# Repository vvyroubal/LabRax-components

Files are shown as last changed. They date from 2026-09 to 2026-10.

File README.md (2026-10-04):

# Lab Rax 1U device brackets

*someone might find it useful :-)*

**1U brackets for a [Lab Rax 10" rack](https://makerworld.com/en/models/1464819-lab-rax-10-server-rack-bolted-version-5u),
bolted to the front *and* rear posts.**

Lab Rax itself — the racks, panels and the rest of the system these brackets
fit into — is the [Lab Rax collection on MakerWorld](https://makerworld.com/en/collections/5813742-lab-rax).

**Everything prints on a Bambu Lab A1 mini.** Its 180 × 180 × 180 mm bed is
the design limit for every part, and each device's 3MF comes already plated
for it.

<p>
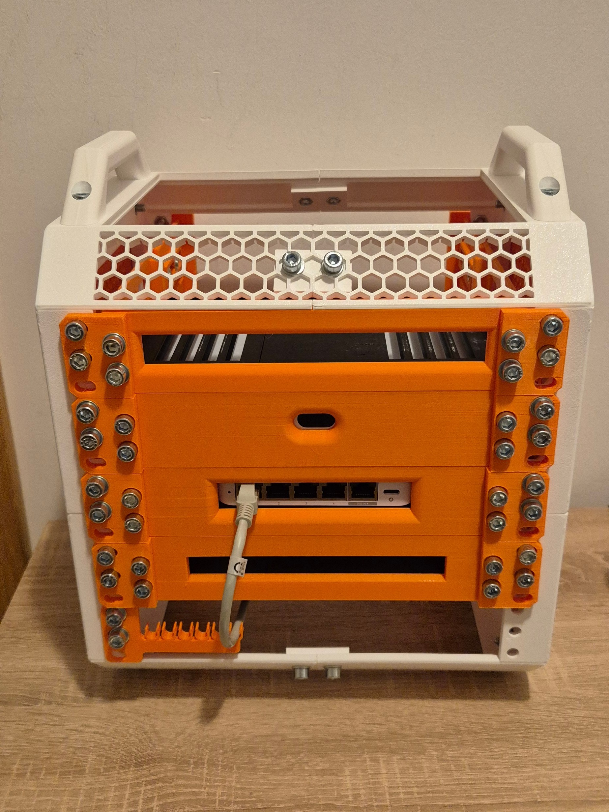
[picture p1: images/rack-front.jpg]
Four brackets in a Lab Rax rack, from the front

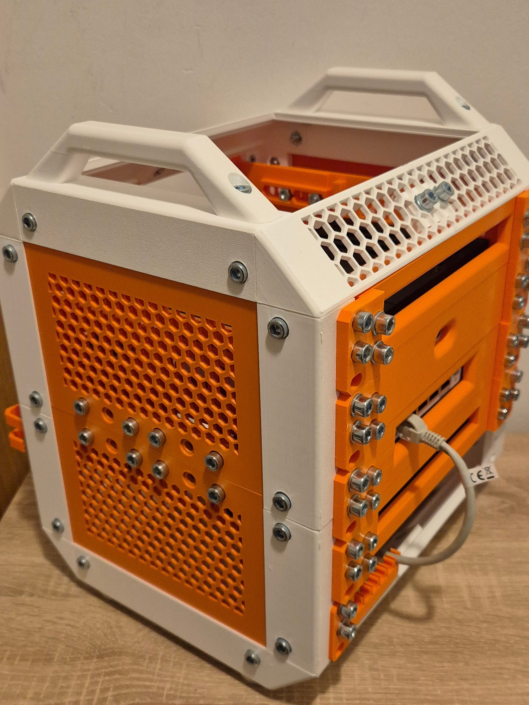
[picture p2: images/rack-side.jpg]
The same rack from the side

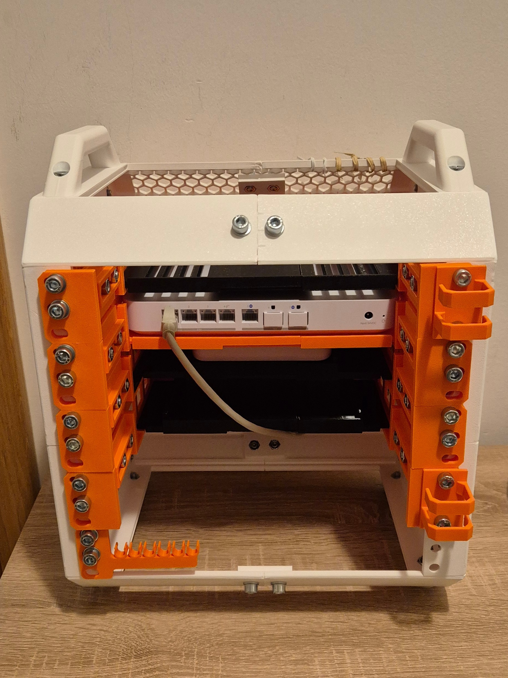
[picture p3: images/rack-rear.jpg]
The same rack from the back

</p>

*Four of these brackets in a Lab Rax, from the front, the side and the back.*

## Quick start

You do not need FreeCAD, Python or anything else in this repository to print
a bracket. The 3MF files are complete.

1. **Print.** Open the 3MF in your device's folder in Bambu Studio and print
   all six plates, in PETG. See [Printing](#printing).
2. **Buy.** 16 × M6 × 12 button-head screws, 4 × M6 nuts, 12 × M6 washers.
   See [Fasteners](#fasteners).
3. **Assemble.** Legs onto the rear posts; sides, tray, device and faceplate
   built on the bench and slid in from the front. See [Assembly](#assembly).

Before committing to the long prints, read [Before you print](#before-you-print):
two small test pieces tell you whether the sliding joint fits on your printer.

## What you can mount

| device | model code | size (mm) | faces the front | print |
|---|---|---|---|---|
| **UniFi Cloud Gateway Fiber** | `UCG-Fiber` | 212.8 × 127.6 × 30, 734 g | its 0.96" display, through an oval window | `ucg-fiber/UCG_Fiber_LabRax-A1mini.3mf` |
| **UniFi Flex Mini 2.5G** | `USW-Flex-2.5G-5` | 117.1 × 90 × 21.2, 206 g | its 5 × 2.5 GbE ports, through an open frame | `usw-flex-mini/USW_Flex_LabRax-A1mini.3mf` |
| **TP-Link Easy Smart switch** | `TL-SG108E` | 158 × 101 × 25 | its 8 × GbE ports, through an open frame | `tl-sg108e/TL_SG108E_LabRax-A1mini.3mf` |
| **Intel NUC, Skull Canyon** | `NUC6i7KYK` | 211 × 116 × 28, 45 W | its front USB and audio, through an open frame | `nuc6i7kyk/NUC6i7KYK_LabRax-A1mini.3mf` |

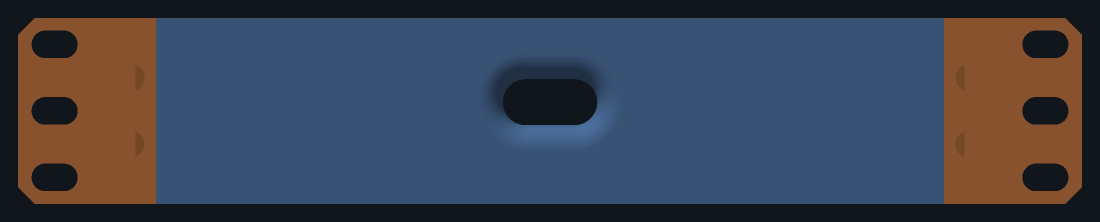
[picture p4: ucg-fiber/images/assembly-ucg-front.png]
the gateway

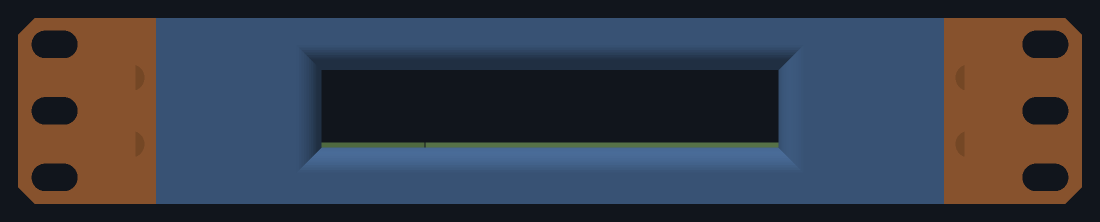
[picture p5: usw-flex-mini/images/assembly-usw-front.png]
the Flex Mini

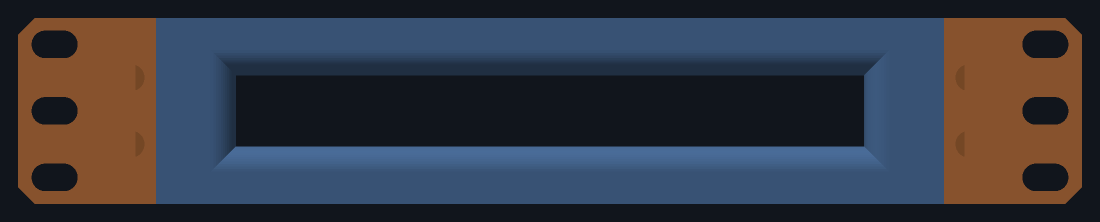
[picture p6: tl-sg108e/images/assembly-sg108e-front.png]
the TP-Link

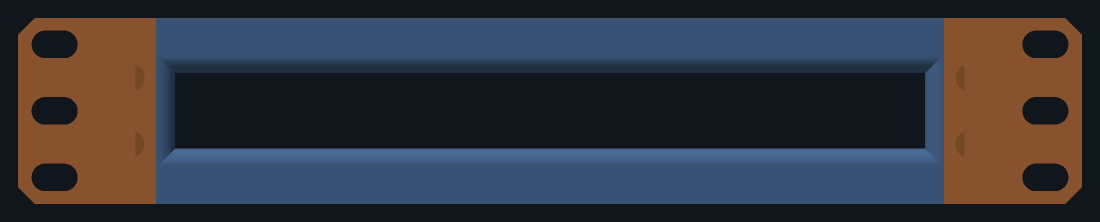
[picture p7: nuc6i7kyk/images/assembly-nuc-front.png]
the NUC


### Will mine fit?

Anything inside this envelope can be carried by the same chassis. It needs a
new device folder with a `device.py` profile in it, and three prints of its
own — see [Adding a device](#adding-a-device).

| | limit | set by |
|---|---|---|
| width | **up to 212.8 mm** | the bay between the rails, 214.0 less clearance |
| depth | **up to 127.6 mm** | the sides' rear stops, 129 mm behind the faceplate |
| height | **up to 33.65 mm** | 1U, less the tray and a flange to cap the device |
| weight | the gateway's 734 g is the heaviest modelled | a 214 × 132 × 6 tray deflects about 0.2 mm under it |
| cooling | passive, or drawing air from underneath | a tray can be slotted, but the front is closed apart from its opening |

A device that fills the bay is held straight by the sides' own rails. One
narrower than **210.8 mm** gets walls on its tray instead, and those walls
need the device to be **204 mm or less**, so widths between about 204 and
210.8 mm are the one gap in the range. A device shorter than the U gets a
plinth under it to centre it in the opening. The faceplate is either a
**window** onto a display or a **frame** onto ports.

What it cannot do: anything over 1U, anything deeper than the rear stops
allow, or anything needing full access to both long faces at once. The
faceplate closes the front apart from its opening, so the busier face has to
go to the back.

## Parts

Seven prints for one device, none over a 180 mm bed.

| part | size (mm) | qty | kit |
|---|---|---|---|
| `side_l` / `side_r` | 33 × 212.5 × 44.5 | 1 each | chassis |
| `leg_l` / `leg_r` | 33 × 91.5 × 44.5 | 1 each | chassis |
| `tray_ucg_l` / `tray_ucg_r` | 136.5 × 131.4 × 9 | 1 each | UCG-Fiber |
| `faceplate_ucg` | 213.6 × 20 × 44.5 | 1 | UCG-Fiber |
| `tray_usw_l` / `tray_usw_r` | 136.5 × 128.4 × 19.6 | 1 each | Flex Mini |
| `faceplate_usw` | 213.6 × 20 × 44.5 | 1 | Flex Mini |
| `tray_sg108e_l` / `tray_sg108e_r` | 136.5 × 128.4 × 17.7 | 1 each | TL-SG108E |
| `faceplate_sg108e` | 213.6 × 20 × 44.5 | 1 | TL-SG108E |
| `tray_nuc_l` / `tray_nuc_r` | 136.5 × 128.4 × 11.2 | 1 each | NUC6i7KYK |
| `faceplate_nuc` | 213.6 × 20 × 44.5 | 1 | NUC6i7KYK |

**Four of the seven are a chassis that takes no notice of what is in it.**
The sides and the rear legs are sized by the rack alone; only the tray pair
and the faceplate are drawn around a device. A second device therefore costs
three prints rather than seven.

A **side** carries the front ear, the side rail, the ledge the tray lands on,
a rear stop, and behind that a **dovetail tongue** along the inner face of the
rail. A **rear leg** carries the rear ear and a **groove** that tongue slides
into. There is no screw between them. At the foot of each leg is a sprung
**catch**, and along the bottom of each rail a notch it runs in: the end stop.

The **tray** comes in halves — at 214 mm it will not fit the bed in any
orientation — lapping 60 mm across the centreline, the left half passing
underneath. Four ⌀5 pegs key them, and they take no screw.

The **faceplate** is the front, in one piece. What is cut in it depends on the
device: a window to see a display through, or a frame opening onto ports. A
flange along its top reaches back over the device so it cannot lift. Its four
nuts slide into slots in its two **ends**, where they stay put.

It is not a front cantilever. The gateway is heavy enough that hanging it off
the front posts alone would work the plastic, so each side runs into a rear
leg that reaches the back posts — four mounting points, twelve screws.

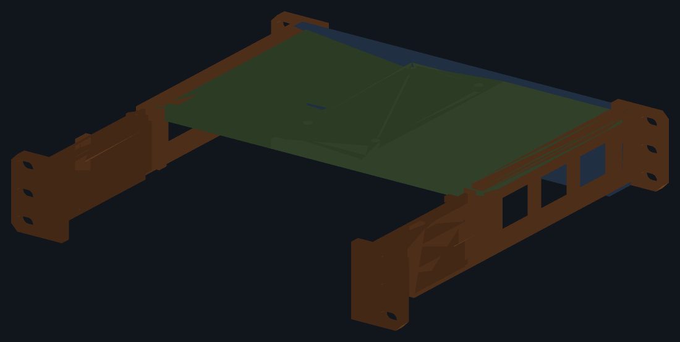
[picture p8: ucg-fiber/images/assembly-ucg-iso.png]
the gateway, assembled


## Printing

**There is one 3MF per device and each carries the chassis too**: six plates,
1–3 the shared chassis, 4–6 that device's own tray pair and faceplate. Open
one, print all six, done. Every plate is labelled in Bambu Studio with the kit
it belongs to. If you build more than one device, plates 1–3 are identical in
every file — print them once per bracket.

| plates | kit | filament | time |
|---|---|---|---|
| 1–3 | chassis (in every file) | 112.1 g | 5 h 46 |
| 4–6 | UCG-Fiber | 149.0 g | 5 h 37 |
| 4–6 | Flex Mini 2.5G | 136.7 g | 5 h 22 |
| 4–6 | TL-SG108E | 142.7 g | 5 h 35 |
| 4–6 | NUC6i7KYK | 133.7 g | 5 h 34 |

A chassis and one kit is about 261 g for the gateway and 249 g for the Flex
Mini. Print in **PETG**: a gateway running IDS/IPS gets warm enough that PLA
is a poor choice around it.

The parts are already turned the way they print: the sides at 45°, the
faceplate stood on edge and upside down so that its flange lies on the bed,
the trays flat. Supports and brims are set per part in the file. Per-plate
figures are in [docs/bom.md](docs/bom.md); settings, orientations and what to
adjust if something is tight are in
[docs/print-settings.md](docs/print-settings.md).

### Before you print

- **Print the two coupons first.** `common/stl/coupon_tongue.stl` and
  `common/stl/coupon_groove.stl` are 25 mm of the side-to-leg runner. Print
  them standing as they are, then slide one into the other. If they bind,
  raise `RUN_FIT` in `common/src/params.py` from 0.25 and rebuild; if they
  rattle, lower it. A dovetail's fit depends on the printer far more than on
  the number, and a side is a two-hour print.
- **Then print one side** and offer it up to the rack. The 0.925 mm per side
  between the rails and the posts is the tightest dimension in the design,
  and a printed rack's post spacing varies.
- **Check the catch moves.** Each leg has a sprung finger at its foot, printed
  flat on the bed with a 1.2 mm slit above it. If the slicer has filled that
  slit with support, clear it out, or the finger cannot move.
- **Measure your device.** Case dimensions are the manufacturers' published
  figures, not calliper measurements, and the weights of the TL-SG108E and
  the NUC are estimates. Before printing a frame faceplate, measure the port
  strip on your unit against the opening given under
  [How each device is held](#how-each-device-is-held).

## Fasteners

**One screw for the whole bracket: M6 × 12.**

| qty | item |
|---|---|
| 16 | M6 × 12 button head |
| 4 | M6 nut — DIN 934, 10 mm across the flats, 5 mm thick |
| 12 | M6 washer — DIN 125 form A, ⌀12.5 |

| qty | where | nut | washer |
|---|---|---|---|
| 12 | bracket to rack: 3 per ear, 4 ears | none — in the post | yes |
| 4 | faceplate, through the front ears | 4 × M6 | no |

The side and the rear leg take none: one slides into the other. The tray
takes none either.

**The rack posts already hold the nuts** for the twelve rack screws, so those
are driven from outside the rack inwards and need no nut of their own.

**The length is not a free choice.** The post's hole is blind at 6 mm, so a
screw that goes more than 6 mm past the ear hits the end and never clamps, and
one that goes much less than 5 mm barely catches the nut. With the ear at
6.5 mm, a 12 mm screw enters 5.5 mm, with 3.5 mm of thread in the nut and half
a millimetre to spare.

**The twelve washers are not optional.** The rack screws go through slots, and
an M6 head is wider than a slot is: without a washer it lands on two crescents
of about 25 mm² and will bury itself in PETG. A washer takes that to
46–60 mm².

**The faceplate's nuts go in from its ends.** Each sits in a slot as tall as
the nut is across its flats, so it cannot turn, and closed in front and
behind, so it cannot fall out. Once the plate is between the sides, the rails
close the open ends too.

## Assembly

Everything with a screw in it is done either behind the rack or on the bench.
No screw has to be reached from inside the rack.

1. **Legs.** Bolt each rear leg to its rear post from behind — three M6 with
   washers — and leave them finger-tight. The grooves face forward.
2. **Nuts.** Slide an M6 nut into each of the four slots in the ends of the
   faceplate, flats top and bottom.
3. **Tray.** On the bench, stand the two sides facing each other and lay the
   tray across their ledges: the **left** half first, then the right half
   onto it, its pegs going down into the left half's sockets. The left half
   cannot be fitted under the right one. The tray spaces the sides.
4. **Device.** Set it straight down onto the tray, its back inside the tray's
   rear lip.
5. **Faceplate.** Lower it from above, behind the ears and in front of the
   device, until its flange sits over the device, and put four M6 through the
   ears into its nuts. It goes on **after** the device: the flange covers the
   device's front edge, and the device cannot be got in underneath it.
6. **Slide it in.** Offer the whole frame to the front of the rack and push:
   each side's tongue runs into its leg's groove, which opens out over its
   first 4 mm to catch it. About 35 mm from home the two catches click into
   their notches. Carry on until the front ears meet the posts.
7. **Bolt up.** Six M6 with washers through the front ears, then tighten the
   six at the back.

**The rack's depth sets itself.** The legs are fixed to the rear posts and the
sides to the front ones; the runner between them takes up whatever the
distance is, from 229 to 257 mm over the outside of the posts.

### The end stop

Undo the six front screws and the frame draws forward **35 mm and stops** —
40 on a 230 mm deep rack, 30 on a 240 — with 17 mm of each tongue still in its
groove.

**At the stop the faceplate can go on or come off in the rack.** It stands
wholly in front of the posts there, flange and all, clear of whatever is in
the U above. So the two sides can be slid in on their own until they click,
the faceplate lowered between them from above, behind the ears, and its four
screws put in from the front; or a faceplate changed without taking anything
else out. On a 240 mm rack the margin to a neighbouring bracket's screw heads
is about a millimetre.

That does not get the tray or the device in. They go in from above too, and
before the faceplate, and at 35 mm out most of the bay is still under
whatever is in the U above. With that U empty, everything can be done in the
rack. Otherwise the tray and the device go into the frame on the bench, as in
the steps above.

Seventeen millimetres of tongue locates the frame; it does not carry it.
**Hold the front up while it is at the stop**, or let it rest on what is
below.

**To take the frame right out**, reach in from the back of the rack and push
the two tabs at the foot of the legs towards the middle, then draw it
forward. Each tab is the tip of its catch; a screwdriver does as well as a
finger.

## How each device is held

| | UCG-Fiber | Flex Mini 2.5G | TL-SG108E | NUC6i7KYK |
|---|---|---|---|---|
| lifted by a plinth | no | 5.625 mm | 3.725 mm | 2.225 mm |
| sits at (z) | 6.0 – 36.0 | 11.625 – 32.825 | 9.725 – 34.725 | 8.225 – 36.225 |
| held sideways by | the rails, 0.6 mm a side | walls on its tray | walls on its tray | the rails, 1.5 mm a side |
| held down by | the faceplate's flange, 0.8 mm over the case | the same | the same | the same |
| held back by | its tray's rear lip | the same | the same | the same |
| opening (mm) | 22.5 × 11.0 window | 109.1 × 18.5 frame | 150 × 17 frame | 179 × 18 frame |
| round-over on the opening | 6 mm | 6 mm | 6 mm | 4 mm |
| tray | solid | solid | solid | slotted for air |

`z` is height above the bottom of the U, which is 44.45 mm tall.

**The gateway** fills the bay, so the rails hold it straight and the ears
overlap its ends by 12.4 mm. Its display faces front through a 22.5 × 11.0
window, slightly larger than the 21.0 × 10.0 display behind it. The window's
top edge sits 7.0 mm below the underside of the faceplate's flange.

**The Flex Mini** is 96.9 mm narrower than the bay and 8.8 mm shorter than the
gateway, and its ports are what you look at, so its tray carries a plinth
that lifts the case until it is centred in the U, and 4 mm walls that hold it
straight. Its frame leaves a 4 mm border each side, 1.85 mm below and 0.85
above. The opening is not centred on the case: centred, an RJ45 plug with its
latch would not go in, so the extra millimetre comes off the top border.

**The TL-SG108E** is held the same way, with a 4 mm border all round its
opening.

**The NUC** fills the bay like the gateway. Its border is 16 mm at each side
— a narrower one would run into the faceplate's nut slots — and 5 mm above and
below. It draws its cooling air through its underside, so its tray is slotted:
fore-and-aft slots open 27% of the width, floor to case. The centre lap stays
solid, because it is the joint holding the tray's halves together.

A frame's border is what keeps the case in, and it does so absolutely rather
than by friction: the case is wider and taller than the hole.

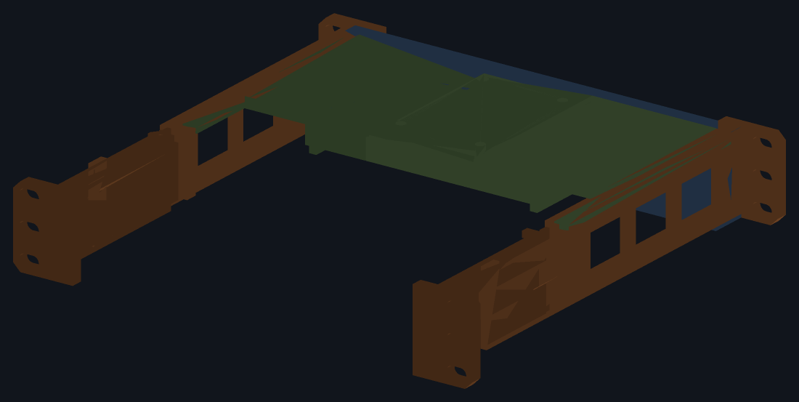
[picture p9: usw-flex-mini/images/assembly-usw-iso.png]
the Flex Mini, assembled


## Orientation and cooling

The gateway's ports and DC input are on one long face and its display on the
other, so its faceplate commits you to **display at the front, cables at the
back**. The two switches are the opposite: **ports at the front**, through the
frame, power at the back. The NUC shows its front USB and audio; everything
else is at the back.

Each side rail carries three windows, and the rear of the bracket is open.
Only the NUC's tray is slotted underneath; the others are solid.

One thing to know about the rear: on the two devices that fill the bay, the
outer 7 mm of each end of the back panel is behind the side's rear stop and
the leg. Keep plugs out of that last 7 mm.

## Compatibility with the rack

Interface numbers were measured off the Lab Rax models themselves rather than
taken from their description, because the published figures are rounded. How
each was obtained is in [docs/measurements.md](docs/measurements.md).

| | value | source |
|---|---|---|
| Faceplate | 254.0 × 44.45 mm (1U) | a Lab Rax 1U mount |
| Screw columns | 236.525 mm apart | rack posts |
| Hole heights in the U | 6.35 / 22.225 / 38.1 mm | EIA-310, confirmed on the posts |
| Screws | M6 | Lab Rax uses M6 throughout |
| Clear width between posts | 222.25 mm | derived from the post holes |
| Clear depth between posts | 170.0 mm | three frame members in the rack's 3MF |
| Front posts to rear posts | 230 or 240 mm outer | 170.0 plus two posts, 30 or 35 mm each |

**The bracket's width comes from the rack.** The posts leave 222.25 mm between
them; 0.925 mm of clearance a side and a 3.2 mm rail give a bay 214.0 mm wide.

**The ears carry clearance slots**, 11.0 × 6.6 mm, giving ±2.3 mm of sideways
adjustment.

**Depth is not a number to trust.** The post's section is 30 × 35 mm and the
mesh does not say which way it faces, so the outer depth is either 230 or
240 mm. The model takes 235 as nominal, and the runner covers 229 – 257 mm:
6 mm shallower than nominal before the leg meets the side's rear stop, 22 mm
deeper before less than 30 mm of tongue is left in the groove.

## Building from source

The parts are modelled in **FreeCAD**, generated by script rather than drawn.
`common/src/params.py` holds every dimension, each device's folder a
`device.py` profile, and `common/src/model.py` builds the bodies from them.
Each part is a PartDesign **Body** of **sketches** driving a **pad** or
**pocket**, so the documents open as something you can edit feature by
feature.

You need:

- **FreeCAD 1.x**, for `make`, `make verify` and `make assembly`. The
  Makefile runs it as a flatpak; set `FREECAD` to your own `freecadcmd` if
  yours is installed another way.
- **Python 3 with NumPy**, for the renders and the plated 3MFs.
- **Bambu Studio**, only for `make plates`. It is also run as a flatpak; set
  `BAMBU` to override.

```sh
make            # build, verify, check fasteners, render, plate
make verify     # re-check the solids against the rack, each device and the bed
make assembly   # put real M6 x 12 screws, nuts and washers in and check them
make plate      # one 3MF in each device's folder, for Bambu Studio
make plates     # slice every plate for real and measure the toolpaths
```

Every `.FCStd` and `.step` embeds a build timestamp, so `make` leaves them
looking modified even when nothing changed. The 3MFs and the STLs are
reproducible. Discard that churn with `git checkout -- '*.FCStd' '*.step'`.

### Adding a device

Add a folder with a `device.py` in it and name that folder in `DIRS` in
`common/src/devices.py`. Nothing else changes. The profile says:

- the case's width, depth and height, and its mass;
- `doc`, what its FreeCAD document and STEP are called;
- `plinth`, how far to lift it above the tray;
- `front`, a `Window` or a `Frame`, with an optional `fillet` to round over
  the opening's front edge;
- `vent=True` if it breathes through its underside and wants a slotted tray.

Then add its three plates to `KITS` in `common/tools/plate.py` and run `make`.

### What is checked

`make verify` measures the **built solids**, not the parameters, so a feature
that silently does nothing is caught rather than assumed away: 197 checks for
the NUC, 194 for the gateway, 193 each for the Flex Mini and the TL-SG108E.
Among them:

- each body is one valid solid, built from sketches, and fits the bed;
- no two parts overlap, and the faceplate and tray still clear what is beside
  them when they are *moved* a fraction of a millimetre, not just where they
  are drawn;
- an M6 passes all twelve rack slots and does not bottom out in the post;
- each leg is held on its tongue every way but along the rack's depth, and
  slides over the whole range claimed;
- the frame stops where it should when drawn out, on racks of either depth,
  and the faceplate can then be lowered into it clear of the U above;
- each faceplate nut slides the length of its slot and is trapped once there;
- the device drops in, is stopped on every face, and cannot be pushed out of
  the front.

`make assembly` places a real M6 × 12, nut and washer at each of the sixteen
positions and asks whether they fit what was actually built: 87 checks per
device.

`make plates` slices every plate and reads the toolpath extents back out of
the G-code, because a part that fits the bed and a print that fits the bed
are not the same claim.

All of this is geometry. None of it tests strength, or how a sliding fit
comes out on a particular printer — which is what the two coupons are for.

### Layout

```
common/
  src/
    params.py       every rack and design dimension, tagged [rack] / [design]
    devices.py      the Device / Window / Frame classes; loads each device's
                    profile, and says where each part's files go
    sk.py           sketch plumbing: planes, polygons, slots, pads, pockets,
                    fillets, and finding edges by where they are
    model.py        four chassis bodies plus three per device, and the coupons
  tools/
    verify.py       193 - 197 checks per device against the rack and the bed
    assembly.py     87 checks with real M6 solids at all sixteen positions
    measure_rack.py re-derives the [rack] numbers from the Lab Rax mesh files
    preview.py      renders each device's images/ from its STLs
    plate.py        arranges the STLs onto A1 mini plates as a Bambu 3MF
    checkplates.py  slices every plate for real and measures the toolpaths
  stl/              side_l, side_r, leg_l, leg_r, and the two test coupons
  cad/  step/       one FreeCAD document and STEP holding every part of every
                    device (it is called UCG_Fiber_LabRax)
ucg-fiber/          one folder per device:
  device.py           its profile: case, mass, plinth, front opening
  stl/                its tray pair and faceplate
  *.FCStd  *.step     the chassis and its three parts, as FreeCAD and STEP
  *.3mf               the chassis and its kit, plated for the A1 mini
  images/             renders of it assembled, and the pictures for MakerWorld
  docs/MAKERWORLD.md  the text posted with that 3MF on MakerWorld
usw-flex-mini/  tl-sg108e/  nuc6i7kyk/
build.py            writes every FCStd, STEP and STL
images/             photographs of the brackets fitted in a rack
docs/
  bom.md            what to print and what to buy, plate by plate
  measurements.md   where the rack's numbers came from
  print-settings.md settings, orientations and fit adjustment
```

## License

MIT; see [LICENSE](LICENSE). Lab Rax itself is not part of this repository
and is published under its own terms on MakerWorld.

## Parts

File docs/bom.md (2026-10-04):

# What to print and what to buy

The print figures here are read out of a real slice and the sizes off the
built solids — nothing is estimated. `make plates` re-slices every plate.

## Print

**Four parts are the chassis and serve every device; three more are that
device's own.** There is one 3MF per device, and each carries the chassis as
well, so whichever you open is a complete build: print all six plates.

| file | plates | filament, time |
|---|---|---|
| `ucg-fiber/UCG_Fiber_LabRax-A1mini.3mf` | 1–3 chassis, 4–6 UCG-Fiber | 261.0 g, 11 h 23 |
| `usw-flex-mini/USW_Flex_LabRax-A1mini.3mf` | 1–3 chassis, 4–6 USW-Flex | 248.7 g, 11 h 09 |
| `tl-sg108e/TL_SG108E_LabRax-A1mini.3mf` | 1–3 chassis, 4–6 TL-SG108E | 254.7 g, 11 h 22 |
| `nuc6i7kyk/NUC6i7KYK_LabRax-A1mini.3mf` | 1–3 chassis, 4–6 NUC6i7KYK | 245.8 g, 11 h 21 |

Every plate carries its own label in Bambu Studio — `Chassis 2 of 3 - right
side`, `UCG-Fiber 3 of 3 - faceplate` — so the tab tells you which kit a plate
belongs to.

| kit | parts | filament | time |
|---|---|---|---|
| chassis | `side_l`, `side_r`, `leg_l`, `leg_r` | 112.1 g | 5 h 46 |
| UCG-Fiber | `tray_ucg_l`, `tray_ucg_r`, `faceplate_ucg` | 149.0 g | 5 h 37 |
| USW-Flex-2.5G-5 | `tray_usw_l`, `tray_usw_r`, `faceplate_usw` | 136.7 g | 5 h 22 |
| TL-SG108E | `tray_sg108e_l`, `tray_sg108e_r`, `faceplate_sg108e` | 142.7 g | 5 h 35 |
| NUC6i7KYK | `tray_nuc_l`, `tray_nuc_r`, `faceplate_nuc` | 133.7 g | 5 h 34 |

**Each bracket needs a chassis of its own.** Plates 1–3 are identical in all
four files, so for a second device print them again from whichever file is
open, then that device's plates 4–6.

Plate by plate:

| plate | part | size (mm) | filament | time | support |
|---|---|---|---|---|---|
| 1 | `side_l` | 33 × 212.5 × 44.5 | 36.1 g | 1 h 56 | yes |
| 2 | `side_r` | 33 × 212.5 × 44.5 | 36.1 g | 1 h 56 | yes |
| 3 | `leg_l` + `leg_r` | 33 × 91.5 × 44.5 each | 40.0 g | 1 h 55 | yes |
| 4 | `tray_ucg_l` | 136.5 × 131.4 × 9 | 49.0 g | 1 h 45 | yes |
| 5 | `tray_ucg_r` | 136.5 × 131.4 × 9 | 57.3 g | 2 h 07 | yes |
| 6 | `faceplate_ucg` | 213.6 × 20 × 44.5 | 42.7 g | 1 h 45 | no |
| 4* | `tray_usw_l` | 136.5 × 128.4 × 19.6 | 42.5 g | 1 h 37 | yes |
| 5* | `tray_usw_r` | 136.5 × 128.4 × 19.6 | 55.5 g | 2 h 05 | yes |
| 6* | `faceplate_usw` | 213.6 × 20 × 44.5 | 38.6 g | 1 h 40 | no |
| 4† | `tray_sg108e_l` | 136.5 × 128.4 × 17.7 | 47.3 g | 1 h 45 | yes |
| 5† | `tray_sg108e_r` | 136.5 × 128.4 × 17.7 | 59.2 g | 2 h 12 | yes |
| 6† | `faceplate_sg108e` | 213.6 × 20 × 44.5 | 36.2 g | 1 h 38 | no |
| 4‡ | `tray_nuc_l` | 136.5 × 128.4 × 11.2 | 44.4 g | 1 h 45 | yes |
| 5‡ | `tray_nuc_r` | 136.5 × 128.4 × 11.2 | 55.4 g | 2 h 12 | yes |
| 6‡ | `faceplate_nuc` | 213.6 × 20 × 44.5 | 33.9 g | 1 h 37 | no |

\* in `USW_Flex_LabRax-A1mini.3mf`, † in `TL_SG108E_LabRax-A1mini.3mf`,
‡ in `NUC6i7KYK_LabRax-A1mini.3mf`; the rows with no mark are in
`UCG_Fiber_LabRax-A1mini.3mf`.

Figures are for PETG at 0.2 mm layers with the profile the 3MFs carry — see
[print-settings.md](print-settings.md).

**Print the two runner coupons first.** `common/stl/coupon_tongue.stl` and
`common/stl/coupon_groove.stl` are 25 mm of the joint between a side and its
leg, and small. They are not in the 3MFs: drop the two STLs
onto a plate in Bambu Studio as they are. The README says what to do with
them.

## Buy

| qty | item |
|---|---|
| **16** | **M6 × 12 button head** |
| **4** | **M6 nut** (DIN 934, 10 mm across the flats, 5 mm thick) |
| **12** | **M6 washer** (DIN 125 form A, ⌀12.5, 1.6 thick) |

That is for one bracket. One screw length does for all of it.

| qty | where | nut | washer |
|---|---|---|---|
| 12 | bracket to rack: 3 per ear, 4 ears | none — in the post | yes |
| 4 | faceplate, through the front ears | 4 × M6 | no |

The twelve rack screws need no nuts: the Lab Rax posts already hold them. The
side and the rear leg take no screw, because the side's tongue slides into
the leg's groove, and neither does the tray, whose halves are keyed by four
pegs.

**The twelve washers are not optional.** Every one of the rack screws goes
through a slot 6.6 mm wide, and an M6 button head is 10.5 across. Without a
washer the head lands on two thin crescents beside the slot, about 25 mm² of
PETG, and tightening will bury it. A ⌀12.5 washer spreads that to 46–60 mm²,
which is what the four faceplate screws, in round counterbored holes, already
have.

### Why 12 mm

The binding constraint is the rack post. Its equipment hole is **blind at
6 mm**: 2 mm of ⌀7.6 clearance, then a 4 mm hex pocket holding the nut. A
screw that goes in more than 6 mm past the ear hits the end of the hole and
never clamps; one that goes in less than about 5 mm barely catches the nut.

That fixes the ear thickness. At **6.5 mm**, a 12 mm screw enters the post
5.5 mm — half a millimetre clear of the bottom — with 3.5 mm of thread in the
nut. Thicker ears and the screw cannot reach; thinner and it bottoms out.

The faceplate is arranged around the same screw:

| joint | how it is made to fit | thread in the nut |
|---|---|---|
| rack | ear 6.5 mm, into the post's own nut | 3.5 mm |
| faceplate | head sunk 1 mm into the ear, nut 1.5 mm behind the plate's front face | 5.0 mm |

`make verify` checks both on every build: that each screw reaches its nut
with at least 3 mm of thread, and that the rack screw does not bottom out.
`make assembly` goes further and puts a real screw, nut and washer at all
sixteen positions, reporting the seat area under each head.

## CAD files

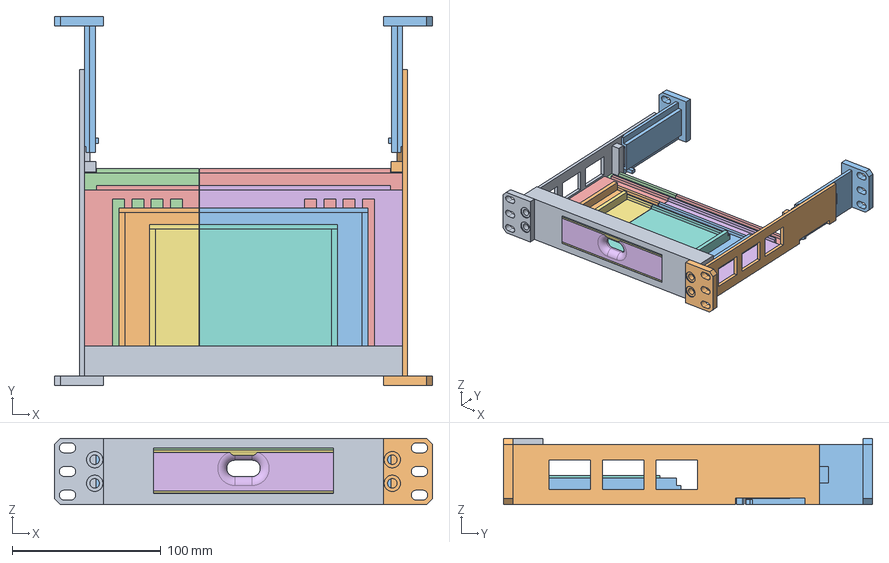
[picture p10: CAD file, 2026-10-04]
common/step/UCG_Fiber_LabRax.step
254.0 x 248.0 x 44.5 mm

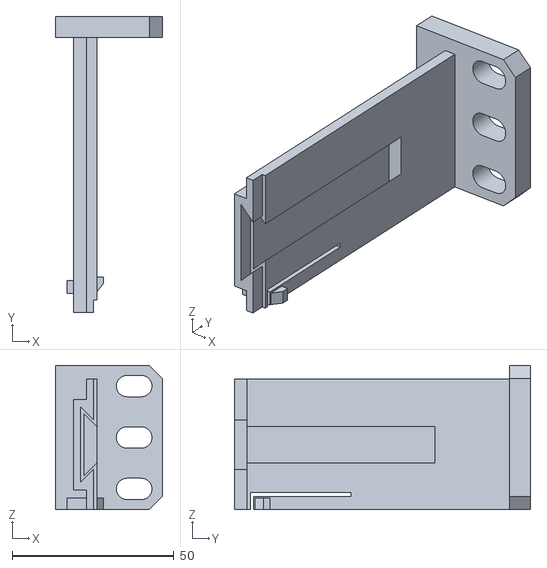
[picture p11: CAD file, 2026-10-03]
common/stl/leg_r.stl
33.0 x 91.5 x 44.5

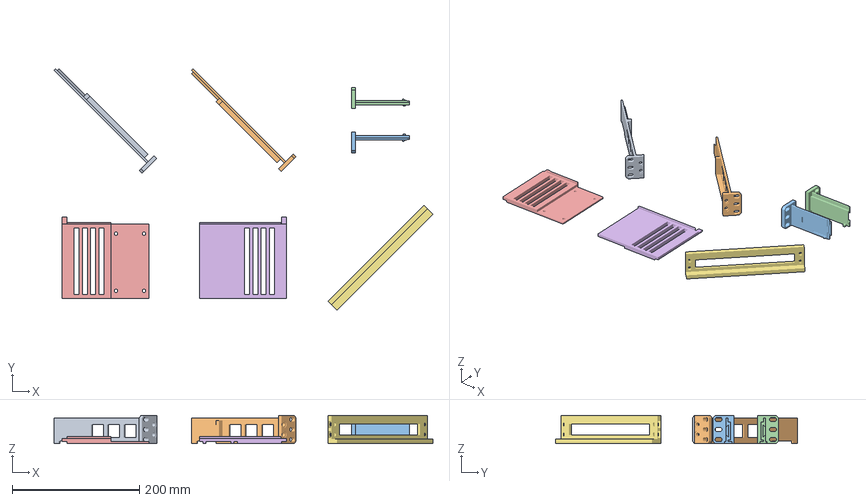
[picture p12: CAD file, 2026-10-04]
nuc6i7kyk/NUC6i7KYK_LabRax-A1mini.3mf
595.4 x 379.4 x 44.5 mm
side_l.stl
side_r.stl
leg_l.stl
leg_r.stl
tray_nuc_l.stl
tray_nuc_r.stl
faceplate_nuc.stl

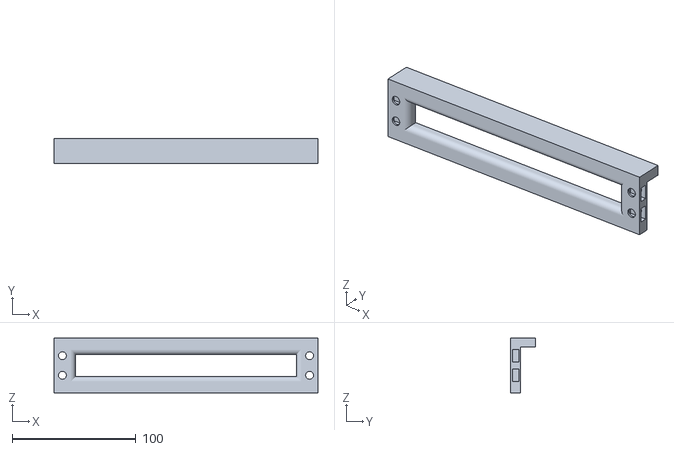
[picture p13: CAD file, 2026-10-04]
nuc6i7kyk/stl/faceplate_nuc.stl
213.6 x 20.0 x 44.5

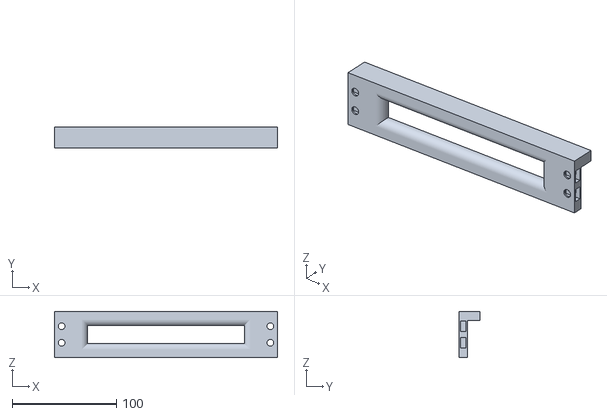
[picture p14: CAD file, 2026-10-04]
tl-sg108e/stl/faceplate_sg108e.stl
213.6 x 20.0 x 44.5

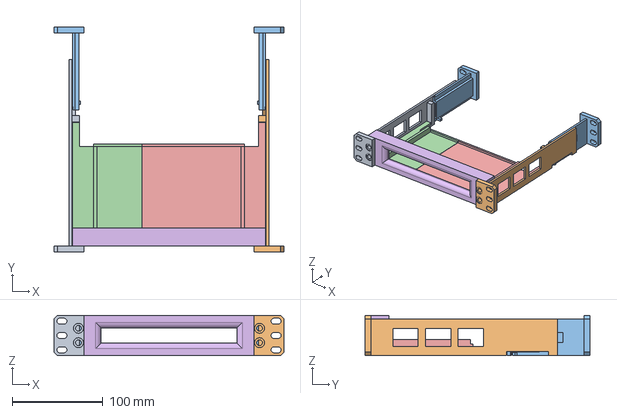
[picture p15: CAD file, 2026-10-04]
tl-sg108e/TL_SG108E_LabRax.step
254.0 x 248.0 x 44.5 mm

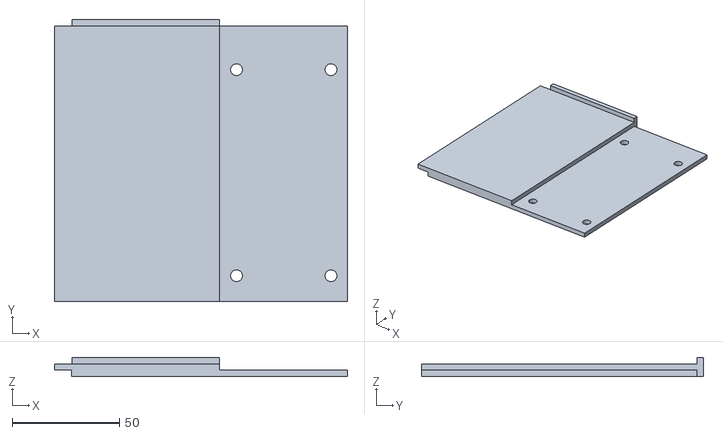
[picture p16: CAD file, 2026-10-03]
ucg-fiber/stl/tray_ucg_l.stl
136.5 x 131.4 x 9.00

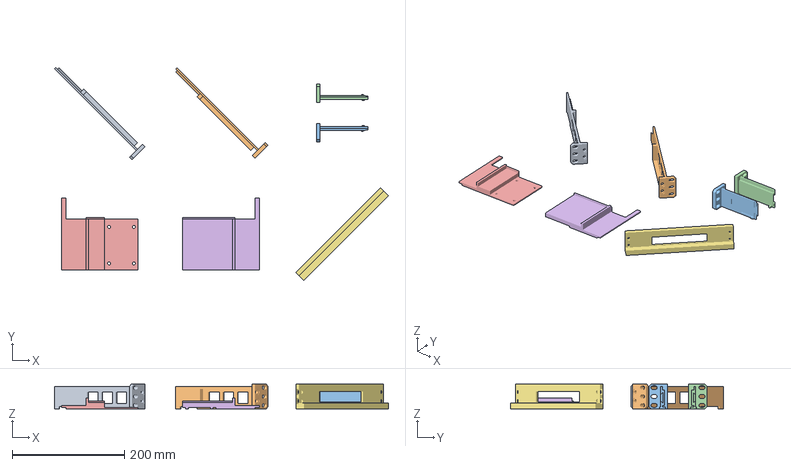
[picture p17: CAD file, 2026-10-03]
usw-flex-mini/USW_Flex_LabRax-A1mini.3mf
595.4 x 379.4 x 44.5 mm
side_l.stl
side_r.stl
leg_l.stl
leg_r.stl
tray_usw_l.stl
tray_usw_r.stl
faceplate_usw.stl

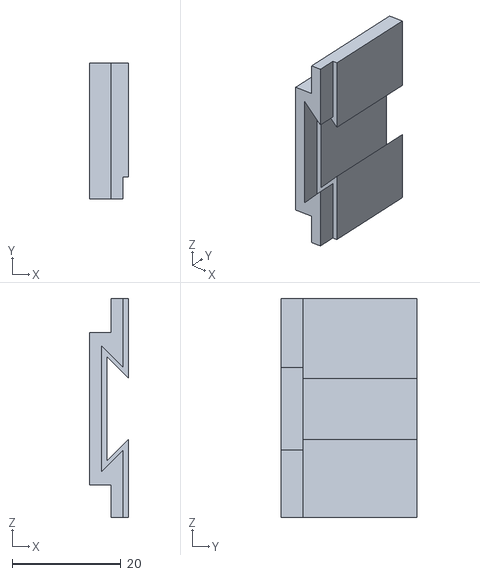
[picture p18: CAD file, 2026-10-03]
common/stl/coupon_groove.stl
7.20 x 25.0 x 40.3

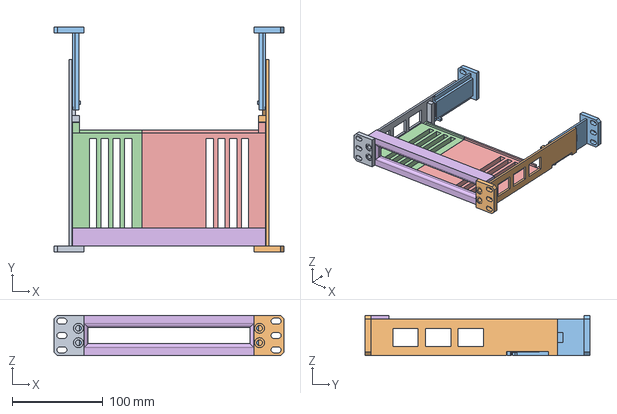
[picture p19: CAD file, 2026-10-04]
nuc6i7kyk/NUC6i7KYK_LabRax.step
254.0 x 248.0 x 44.5 mm

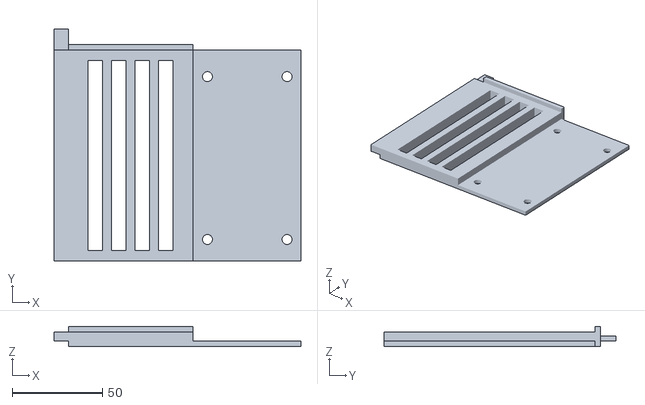
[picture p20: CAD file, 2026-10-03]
nuc6i7kyk/stl/tray_nuc_l.stl
136.5 x 128.4 x 11.2

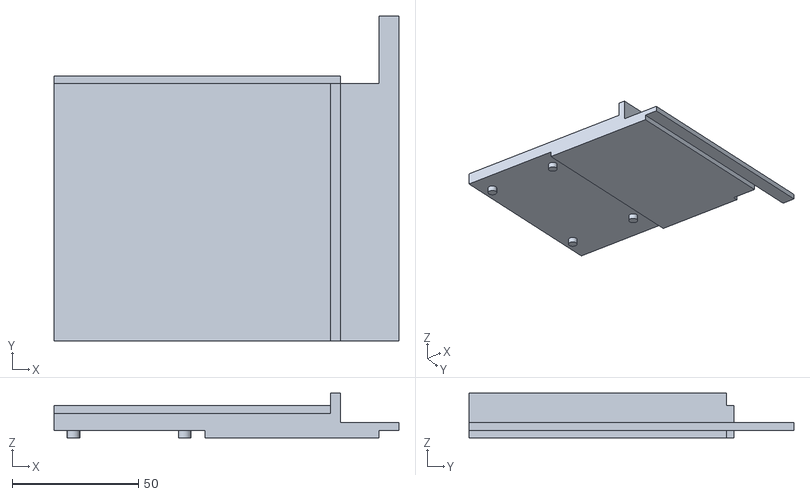
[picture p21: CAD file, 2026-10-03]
tl-sg108e/stl/tray_sg108e_r.stl
136.5 x 128.4 x 17.7

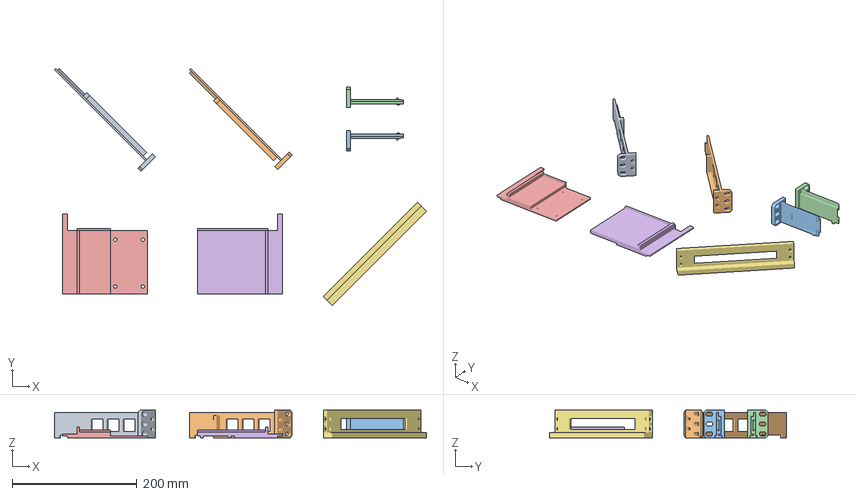
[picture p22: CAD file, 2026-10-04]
tl-sg108e/TL_SG108E_LabRax-A1mini.3mf
595.4 x 379.4 x 44.5 mm
side_l.stl
side_r.stl
leg_l.stl
leg_r.stl
tray_sg108e_l.stl
tray_sg108e_r.stl
faceplate_sg108e.stl

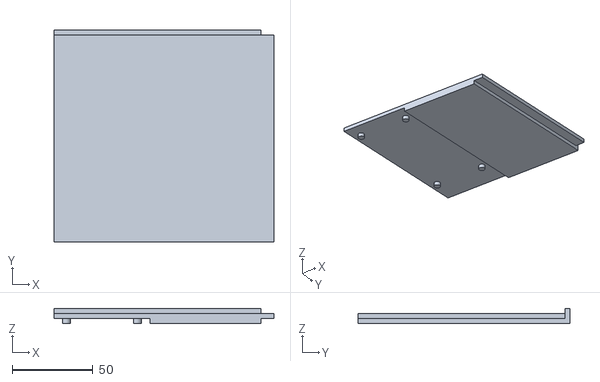
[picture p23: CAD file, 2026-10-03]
ucg-fiber/stl/tray_ucg_r.stl
136.5 x 131.4 x 9.00

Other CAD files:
ucg-fiber/UCG_Fiber_LabRax-A1mini.3mf
usw-flex-mini/stl/faceplate_usw.stl
ucg-fiber/UCG_Fiber_LabRax.step
usw-flex-mini/stl/tray_usw_l.stl
common/cad/UCG_Fiber_LabRax.FCStd
common/stl/coupon_tongue.stl
common/stl/leg_l.stl
common/stl/side_l.stl
common/stl/side_r.stl
nuc6i7kyk/NUC6i7KYK_LabRax.FCStd
nuc6i7kyk/stl/tray_nuc_r.stl
tl-sg108e/TL_SG108E_LabRax.FCStd
tl-sg108e/stl/tray_sg108e_l.stl
ucg-fiber/UCG_Fiber_LabRax.FCStd
ucg-fiber/stl/faceplate_ucg.stl
usw-flex-mini/USW_Flex_LabRax.FCStd
usw-flex-mini/USW_Flex_LabRax.step
usw-flex-mini/stl/tray_usw_r.stl

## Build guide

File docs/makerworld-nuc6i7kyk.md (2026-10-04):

# MakerWorld listing: NUC6i7KYK_LabRax-A1mini.3mf

Text to post with `nuc6i7kyk/NUC6i7KYK_LabRax-A1mini.3mf`. Paste each part into the matching field.

## Title

Lab Rax 1U bracket for Intel NUC6i7KYK (Skull Canyon), A1 mini

## Summary

A 1U bracket that carries an Intel NUC6i7KYK (Skull Canyon) in a Lab Rax 10 inch rack, bolted to the front and rear posts, on a slotted tray that lets it breathe. Every part fits an A1 mini.

## Tags

Lab Rax, 10 inch rack, 1U, Intel NUC, NUC6i7KYK, Skull Canyon, rack mount, homelab, A1 mini

## Pictures

Isometric views from FreeCAD, in `nuc6i7kyk/images/`, 1200 x 1600 (3:4) on white:

1. `makerworld-nuc-assembled.png` — cover picture: the bracket with the
   device in place and all sixteen screws fitted.
2. `makerworld-nuc-empty.png` — the bracket without the device, showing the
   tray and the runners at the back.
3. `makerworld-nuc-exploded.png` — the seven printed parts and the device,
   drawn apart to show how they go together.

The device is shown as a plain translucent block the size of its case.

## Description

**A 1U bracket for the Intel NUC6i7KYK, "Skull Canyon", for a Lab Rax 10 inch rack.**

It bolts to the front and the rear posts, so the device is carried at four
points rather than hung off the front. It goes in like a drawer: two legs
bolt to the rear posts, and the rest is built on the bench and slid in from
the front. No screw has to be reached from inside the rack.

The rack itself is not included. It is the Lab Rax bolted 5U rack:
https://makerworld.com/en/models/1464819-lab-rax-10-server-rack-bolted-version-5u
and the rest of the system is in the Lab Rax collection:
https://makerworld.com/en/collections/5813742-lab-rax

**The device**

Intel NUC6i7KYK, "Skull Canyon", 211 x 116 x 28 mm.

The NUC's front USB ports and audio jack face the front through an open frame in the faceplate, 179 x 18 mm, with a rounded front edge. Everything else is at the back.

The NUC fills the bay, so the bracket's own side rails hold it straight. It draws its cooling air through its underside, so the tray under it is slotted from front to back.

**What is in the file**

Six plates, already arranged for a Bambu Lab A1 mini (180 x 180 mm bed):

- Plate 1: left side
- Plate 2: right side
- Plate 3: both rear legs
- Plate 4: left half of the tray
- Plate 5: right half of the tray
- Plate 6: faceplate

Every part is already turned the way it prints, and supports and brims are
set per part. Open the file and print all six plates.

Plates 1 to 3 are a chassis that is the same for every device in this series.
Plates 4 to 6 are made for this device.

**Printing**

- Material: PETG. PLA will work in a cool room, but a warm device makes it a
  poor choice.
- Profile: 0.20 mm Standard for the A1 mini, as carried in the file. 2 walls,
  15% infill.
- Filament: about 246 g for all six plates.
- Time: about 11 h 21 min for all six plates.

Each rear leg has a small sprung catch at its foot, printed flat on the bed
with a thin slit above it. When the legs come off the plate, check that slit
is clear and pick out any support left in it, or the catch cannot move.

**Hardware to buy**

- 16 x M6 x 12 button head screws
- 4 x M6 nuts
- 12 x M6 washers (12.5 mm outside diameter)

The rack's posts already hold the nuts for the twelve rack screws. The four
loose nuts are for the faceplate. The washers are needed: the rack screws go
through slots, and a bare screw head will sink into the plastic.

**Assembly**

1. Bolt each rear leg to its rear post from behind, three screws with
   washers. Leave them finger-tight. The grooves face forward.
2. Slide a nut into each of the four slots in the ends of the faceplate.
3. On the bench, stand the two sides facing each other and lay the tray
   across their ledges: the left half first, then the right half onto it.
4. Set the device down onto the tray.
5. Lower the faceplate from above, behind the ears and in front of the
   device, and put four screws through the ears into its nuts. The faceplate
   goes on after the device, not before.
6. Slide the whole frame into the rack from the front. Each side runs into
   the groove of its leg. About 35 mm from home the two catches click.
7. Put six screws with washers through the front ears, then tighten the six
   at the back.

To take it out again, undo the six front screws and draw the frame forward.
It stops after about 35 mm. To remove it completely, reach in from the back
of the rack and push the two tabs at the foot of the legs towards the middle.

**Good to know**

- The sides slide into the legs on a printed dovetail, and how freely that
  runs depends on the printer. Two small test pieces for it are on GitHub
  (`common/stl/coupon_tongue.stl` and `coupon_groove.stl`). Print those first:
  they are small, and they tell you whether the fit suits your printer before
  you print a two-hour side.
- The rack's depth sets itself. The joint between side and leg slides, and
  covers 229 to 257 mm over the outside of the posts.
- The gap between the bracket and the rack's posts is under a millimetre a
  side. Print one side first and offer it up to your rack.
- The outer 7 mm at each end of the NUC's back panel sits behind the
  bracket's rear stops. Keep plugs out of that last 7 mm.
- Before printing the faceplate, check the front ports on your unit against
  the 179 x 18 mm opening. Case dimensions are Intel's published figures.

**Source, other devices and full documentation**

https://github.com/vvyroubal/LabRax-components

The parts are generated by a FreeCAD script, so every dimension can be
changed and the files rebuilt. The repository also has the STL, STEP and
FreeCAD files, brackets for other devices on the same chassis, and what to
change if a fit is tight on your printer. MIT licence.

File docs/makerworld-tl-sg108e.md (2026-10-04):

# MakerWorld listing: TL_SG108E_LabRax-A1mini.3mf

Text to post with `tl-sg108e/TL_SG108E_LabRax-A1mini.3mf`. Paste each part into the matching field.

## Title

Lab Rax 1U bracket for TP-Link TL-SG108E, A1 mini

## Summary

A 1U bracket that carries a TP-Link TL-SG108E 8-port switch in a Lab Rax 10 inch rack, bolted to the front and rear posts. Ports at the front. Every part fits an A1 mini.

## Tags

Lab Rax, 10 inch rack, 1U, TP-Link, TL-SG108E, switch, rack mount, homelab, A1 mini

## Pictures

Isometric views from FreeCAD, in `tl-sg108e/images/`, 1200 x 1600 (3:4) on white:

1. `makerworld-sg108e-assembled.png` — cover picture: the bracket with the
   device in place and all sixteen screws fitted.
2. `makerworld-sg108e-empty.png` — the bracket without the device, showing the
   tray and the runners at the back.
3. `makerworld-sg108e-exploded.png` — the seven printed parts and the device,
   drawn apart to show how they go together.

The device is shown as a plain translucent block the size of its case.

## Description

**A 1U bracket for the TP-Link TL-SG108E Easy Smart switch, for a Lab Rax 10 inch rack.**

It bolts to the front and the rear posts, so the device is carried at four
points rather than hung off the front. It goes in like a drawer: two legs
bolt to the rear posts, and the rest is built on the bench and slid in from
the front. No screw has to be reached from inside the rack.

The rack itself is not included. It is the Lab Rax bolted 5U rack:
https://makerworld.com/en/models/1464819-lab-rax-10-server-rack-bolted-version-5u
and the rest of the system is in the Lab Rax collection:
https://makerworld.com/en/collections/5813742-lab-rax

**The device**

TP-Link TL-SG108E Easy Smart switch, 158 x 101 x 25 mm.

The switch's eight ports face the front through an open frame in the faceplate, 150 x 17 mm, with a rounded front edge. Its power jack is at the back.

The switch is narrower than the rack, so its tray carries walls that hold it straight and a plinth that lifts it until it is centred in the U. The frame leaves a 4 mm border all round, so the switch cannot come out through the front.

**What is in the file**

Six plates, already arranged for a Bambu Lab A1 mini (180 x 180 mm bed):

- Plate 1: left side
- Plate 2: right side
- Plate 3: both rear legs
- Plate 4: left half of the tray
- Plate 5: right half of the tray
- Plate 6: faceplate

Every part is already turned the way it prints, and supports and brims are
set per part. Open the file and print all six plates.

Plates 1 to 3 are a chassis that is the same for every device in this series.
Plates 4 to 6 are made for this device.

**Printing**

- Material: PETG. PLA will work in a cool room, but a warm device makes it a
  poor choice.
- Profile: 0.20 mm Standard for the A1 mini, as carried in the file. 2 walls,
  15% infill.
- Filament: about 255 g for all six plates.
- Time: about 11 h 22 min for all six plates.

Each rear leg has a small sprung catch at its foot, printed flat on the bed
with a thin slit above it. When the legs come off the plate, check that slit
is clear and pick out any support left in it, or the catch cannot move.

**Hardware to buy**

- 16 x M6 x 12 button head screws
- 4 x M6 nuts
- 12 x M6 washers (12.5 mm outside diameter)

The rack's posts already hold the nuts for the twelve rack screws. The four
loose nuts are for the faceplate. The washers are needed: the rack screws go
through slots, and a bare screw head will sink into the plastic.

**Assembly**

1. Bolt each rear leg to its rear post from behind, three screws with
   washers. Leave them finger-tight. The grooves face forward.
2. Slide a nut into each of the four slots in the ends of the faceplate.
3. On the bench, stand the two sides facing each other and lay the tray
   across their ledges: the left half first, then the right half onto it.
4. Set the device down onto the tray.
5. Lower the faceplate from above, behind the ears and in front of the
   device, and put four screws through the ears into its nuts. The faceplate
   goes on after the device, not before.
6. Slide the whole frame into the rack from the front. Each side runs into
   the groove of its leg. About 35 mm from home the two catches click.
7. Put six screws with washers through the front ears, then tighten the six
   at the back.

To take it out again, undo the six front screws and draw the frame forward.
It stops after about 35 mm. To remove it completely, reach in from the back
of the rack and push the two tabs at the foot of the legs towards the middle.

**Good to know**

- The sides slide into the legs on a printed dovetail, and how freely that
  runs depends on the printer. Two small test pieces for it are on GitHub
  (`common/stl/coupon_tongue.stl` and `coupon_groove.stl`). Print those first:
  they are small, and they tell you whether the fit suits your printer before
  you print a two-hour side.
- The rack's depth sets itself. The joint between side and leg slides, and
  covers 229 to 257 mm over the outside of the posts.
- The gap between the bracket and the rack's posts is under a millimetre a
  side. Print one side first and offer it up to your rack.
- Before printing the faceplate, measure the port strip on your unit against
  the 150 x 17 mm opening. Case dimensions are TP-Link's published figures.

**Source, other devices and full documentation**

https://github.com/vvyroubal/LabRax-components

The parts are generated by a FreeCAD script, so every dimension can be
changed and the files rebuilt. The repository also has the STL, STEP and
FreeCAD files, brackets for other devices on the same chassis, and what to
change if a fit is tight on your printer. MIT licence.

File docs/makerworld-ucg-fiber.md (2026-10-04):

# MakerWorld listing: UCG_Fiber_LabRax-A1mini.3mf

Text to post with `ucg-fiber/UCG_Fiber_LabRax-A1mini.3mf`. Paste each part into the matching field.

## Title

Lab Rax 1U bracket for UniFi Cloud Gateway Fiber (UCG-Fiber), A1 mini

## Summary

A 1U bracket that carries a UniFi Cloud Gateway Fiber in a Lab Rax 10 inch rack, bolted to the front and rear posts. Display at the front, cables at the back. Every part fits an A1 mini.

## Tags

Lab Rax, 10 inch rack, 1U, UniFi, UCG-Fiber, Cloud Gateway Fiber, rack mount, homelab, A1 mini

## Pictures

Isometric views from FreeCAD, in `ucg-fiber/images/`, 1200 x 1600 (3:4) on white:

1. `makerworld-ucg-assembled.png` — cover picture: the bracket with the
   device in place and all sixteen screws fitted.
2. `makerworld-ucg-empty.png` — the bracket without the device, showing the
   tray and the runners at the back.
3. `makerworld-ucg-exploded.png` — the seven printed parts and the device,
   drawn apart to show how they go together.

The device is shown as a plain translucent block the size of its case.

## Description

**A 1U bracket for the UniFi Cloud Gateway Fiber (UCG-Fiber), for a Lab Rax 10 inch rack.**

It bolts to the front and the rear posts, so the device is carried at four
points rather than hung off the front. It goes in like a drawer: two legs
bolt to the rear posts, and the rest is built on the bench and slid in from
the front. No screw has to be reached from inside the rack.

The rack itself is not included. It is the Lab Rax bolted 5U rack:
https://makerworld.com/en/models/1464819-lab-rax-10-server-rack-bolted-version-5u
and the rest of the system is in the Lab Rax collection:
https://makerworld.com/en/collections/5813742-lab-rax

**The device**

UniFi Cloud Gateway Fiber (UCG-Fiber), 212.8 x 127.6 x 30 mm, 734 g.

The gateway's display shows through a small oval window in the faceplate. Its ports and power are on the opposite face, so the cables leave from the back of the rack.

The gateway fills the bay, so the bracket's own side rails hold it straight. A flange on the faceplate sits over its top and a low lip on the tray sits behind it.

**What is in the file**

Six plates, already arranged for a Bambu Lab A1 mini (180 x 180 mm bed):

- Plate 1: left side
- Plate 2: right side
- Plate 3: both rear legs
- Plate 4: left half of the tray
- Plate 5: right half of the tray
- Plate 6: faceplate

Every part is already turned the way it prints, and supports and brims are
set per part. Open the file and print all six plates.

Plates 1 to 3 are a chassis that is the same for every device in this series.
Plates 4 to 6 are made for this device.

**Printing**

- Material: PETG. PLA will work in a cool room, but a warm device makes it a
  poor choice.
- Profile: 0.20 mm Standard for the A1 mini, as carried in the file. 2 walls,
  15% infill.
- Filament: about 261 g for all six plates.
- Time: about 11 h 23 min for all six plates.

Each rear leg has a small sprung catch at its foot, printed flat on the bed
with a thin slit above it. When the legs come off the plate, check that slit
is clear and pick out any support left in it, or the catch cannot move.

**Hardware to buy**

- 16 x M6 x 12 button head screws
- 4 x M6 nuts
- 12 x M6 washers (12.5 mm outside diameter)

The rack's posts already hold the nuts for the twelve rack screws. The four
loose nuts are for the faceplate. The washers are needed: the rack screws go
through slots, and a bare screw head will sink into the plastic.

**Assembly**

1. Bolt each rear leg to its rear post from behind, three screws with
   washers. Leave them finger-tight. The grooves face forward.
2. Slide a nut into each of the four slots in the ends of the faceplate.
3. On the bench, stand the two sides facing each other and lay the tray
   across their ledges: the left half first, then the right half onto it.
4. Set the device down onto the tray.
5. Lower the faceplate from above, behind the ears and in front of the
   device, and put four screws through the ears into its nuts. The faceplate
   goes on after the device, not before.
6. Slide the whole frame into the rack from the front. Each side runs into
   the groove of its leg. About 35 mm from home the two catches click.
7. Put six screws with washers through the front ears, then tighten the six
   at the back.

To take it out again, undo the six front screws and draw the frame forward.
It stops after about 35 mm. To remove it completely, reach in from the back
of the rack and push the two tabs at the foot of the legs towards the middle.

**Good to know**

- The sides slide into the legs on a printed dovetail, and how freely that
  runs depends on the printer. Two small test pieces for it are on GitHub
  (`common/stl/coupon_tongue.stl` and `coupon_groove.stl`). Print those first:
  they are small, and they tell you whether the fit suits your printer before
  you print a two-hour side.
- The rack's depth sets itself. The joint between side and leg slides, and
  covers 229 to 257 mm over the outside of the posts.
- The gap between the bracket and the rack's posts is under a millimetre a
  side. Print one side first and offer it up to your rack.
- The outer 7 mm at each end of the gateway's back panel sits behind the
  bracket's rear stops. Keep plugs out of that last 7 mm.
- The window is 22.5 x 11 mm, a little larger than the 21 x 10 mm display.
  If the display on your unit sits elsewhere, its position is one number in
  the source on GitHub.

**Source, other devices and full documentation**

https://github.com/vvyroubal/LabRax-components

The parts are generated by a FreeCAD script, so every dimension can be
changed and the files rebuilt. The repository also has the STL, STEP and
FreeCAD files, brackets for other devices on the same chassis, and what to
change if a fit is tight on your printer. MIT licence.

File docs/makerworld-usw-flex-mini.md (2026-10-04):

# MakerWorld listing: USW_Flex_LabRax-A1mini.3mf

Text to post with `usw-flex-mini/USW_Flex_LabRax-A1mini.3mf`. Paste each part into the matching field.

## Title

Lab Rax 1U bracket for UniFi Flex Mini 2.5G (USW-Flex-2.5G-5), A1 mini

## Summary

A 1U bracket that carries a UniFi Flex Mini 2.5G in a Lab Rax 10 inch rack, bolted to the front and rear posts. Ports at the front. Every part fits an A1 mini.

## Tags

Lab Rax, 10 inch rack, 1U, UniFi, USW-Flex-2.5G-5, Flex Mini, switch, rack mount, homelab, A1 mini

## Pictures

Isometric views from FreeCAD, in `usw-flex-mini/images/`, 1200 x 1600 (3:4) on white:

1. `makerworld-usw-assembled.png` — cover picture: the bracket with the
   device in place and all sixteen screws fitted.
2. `makerworld-usw-empty.png` — the bracket without the device, showing the
   tray and the runners at the back.
3. `makerworld-usw-exploded.png` — the seven printed parts and the device,
   drawn apart to show how they go together.

The device is shown as a plain translucent block the size of its case.

## Description

**A 1U bracket for the UniFi Flex Mini 2.5G (USW-Flex-2.5G-5), for a Lab Rax 10 inch rack.**

It bolts to the front and the rear posts, so the device is carried at four
points rather than hung off the front. It goes in like a drawer: two legs
bolt to the rear posts, and the rest is built on the bench and slid in from
the front. No screw has to be reached from inside the rack.

The rack itself is not included. It is the Lab Rax bolted 5U rack:
https://makerworld.com/en/models/1464819-lab-rax-10-server-rack-bolted-version-5u
and the rest of the system is in the Lab Rax collection:
https://makerworld.com/en/collections/5813742-lab-rax

**The device**

UniFi Flex Mini 2.5G (USW-Flex-2.5G-5), 117.1 x 90 x 21.2 mm, 206 g.

The switch's five ports face the front through an open frame in the faceplate, 109.1 x 18.5 mm, with a rounded front edge.

The switch is much narrower than the rack, so its tray carries walls that hold it straight and a plinth that lifts it until it is centred in the U. The frame's border is smaller than the case, so the switch cannot come out through the front.

**What is in the file**

Six plates, already arranged for a Bambu Lab A1 mini (180 x 180 mm bed):

- Plate 1: left side
- Plate 2: right side
- Plate 3: both rear legs
- Plate 4: left half of the tray
- Plate 5: right half of the tray
- Plate 6: faceplate

Every part is already turned the way it prints, and supports and brims are
set per part. Open the file and print all six plates.

Plates 1 to 3 are a chassis that is the same for every device in this series.
Plates 4 to 6 are made for this device.

**Printing**

- Material: PETG. PLA will work in a cool room, but a warm device makes it a
  poor choice.
- Profile: 0.20 mm Standard for the A1 mini, as carried in the file. 2 walls,
  15% infill.
- Filament: about 249 g for all six plates.
- Time: about 11 h 09 min for all six plates.

Each rear leg has a small sprung catch at its foot, printed flat on the bed
with a thin slit above it. When the legs come off the plate, check that slit
is clear and pick out any support left in it, or the catch cannot move.

**Hardware to buy**

- 16 x M6 x 12 button head screws
- 4 x M6 nuts
- 12 x M6 washers (12.5 mm outside diameter)

The rack's posts already hold the nuts for the twelve rack screws. The four
loose nuts are for the faceplate. The washers are needed: the rack screws go
through slots, and a bare screw head will sink into the plastic.

**Assembly**

1. Bolt each rear leg to its rear post from behind, three screws with
   washers. Leave them finger-tight. The grooves face forward.
2. Slide a nut into each of the four slots in the ends of the faceplate.
3. On the bench, stand the two sides facing each other and lay the tray
   across their ledges: the left half first, then the right half onto it.
4. Set the device down onto the tray.
5. Lower the faceplate from above, behind the ears and in front of the
   device, and put four screws through the ears into its nuts. The faceplate
   goes on after the device, not before.
6. Slide the whole frame into the rack from the front. Each side runs into
   the groove of its leg. About 35 mm from home the two catches click.
7. Put six screws with washers through the front ears, then tighten the six
   at the back.

To take it out again, undo the six front screws and draw the frame forward.
It stops after about 35 mm. To remove it completely, reach in from the back
of the rack and push the two tabs at the foot of the legs towards the middle.

**Good to know**

- The sides slide into the legs on a printed dovetail, and how freely that
  runs depends on the printer. Two small test pieces for it are on GitHub
  (`common/stl/coupon_tongue.stl` and `coupon_groove.stl`). Print those first:
  they are small, and they tell you whether the fit suits your printer before
  you print a two-hour side.
- The rack's depth sets itself. The joint between side and leg slides, and
  covers 229 to 257 mm over the outside of the posts.
- The gap between the bracket and the rack's posts is under a millimetre a
  side. Print one side first and offer it up to your rack.
- Before printing the faceplate, measure the port strip on your unit against
  the 109.1 x 18.5 mm opening. Case dimensions are Ubiquiti's published
  figures.
- The opening is deliberately not centred on the case: it is shifted so that
  an RJ45 plug with its latch goes in.

**Source, other devices and full documentation**

https://github.com/vvyroubal/LabRax-components

The parts are generated by a FreeCAD script, so every dimension can be
changed and the files rebuilt. The repository also has the STL, STEP and
FreeCAD files, brackets for other devices on the same chassis, and what to
change if a fit is tight on your printer. MIT licence.

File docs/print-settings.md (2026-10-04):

# Printing

Everything is plated for a **Bambu Lab A1 mini** (180 × 180 × 180 mm).

Each device's folder holds one 3MF. It is a full Bambu Studio project: six
plates, every part already turned the way it prints, supports and brims set
per part, and the A1 mini presets carried with it. Open it and print.

| plate | parts |
|---|---|
| 1 | `side_l` |
| 2 | `side_r` |
| 3 | `leg_l` and `leg_r` |
| 4 | the device's left tray half |
| 5 | the device's right tray half |
| 6 | the device's faceplate |

Filament and time for each plate are in [bom.md](bom.md).

## Material

**PETG.** The UCG-Fiber is fanless and dissipates its heat through its case;
with IDS/IPS running it gets warm enough that PLA creeping under a 734 g
device is a real risk. ASA or PC are fine too. PLA will work in a cool room
but is not the right choice here.

## Settings

The 3MFs carry Bambu Studio's stock `0.20mm Standard @BBL A1M` process with
`Generic PETG @BBL A1M`, and the figures in [bom.md](bom.md) are for exactly
that:

| | |
|---|---|
| Layer height | 0.2 mm |
| Walls | 2 |
| Infill | 15 %, grid |
| Brim | 5 mm, automatic; turned off for the trays and the faceplate |
| Support | on for the sides, the legs and the trays; off for the faceplate |
| Plate | textured PEI |

Sliced with Bambu Studio 2.8.2. Nothing stops you raising the wall count or
the infill in Bambu Studio before printing — four walls make the 3.2 mm side
rails solid — at the cost of more filament and time than the tables say.

## Orientation

All of this is already applied in the 3MFs. It matters only if you plate the
STLs yourself.

- **`side_l` / `side_r`** — standing on the rail's bottom edge, as exported,
  and turned 45°: at 212.5 mm a side only fits the bed cornerwise. Support
  is on, for the notch along the foot of the rail and the tops of the windows
  and slots.
- **`leg_l` / `leg_r`** — standing as exported, turned 90°, both on one
  plate. Support is on. The sprung catch at the foot of each leg prints flat
  on the bed, with the plate above it bridging a 1.2 mm slit: **check that
  slit is clear** when the print comes off, and pick out any support left in
  it, or the catch cannot move.
- **Tray halves** — flat, as exported, with no brim: they are large flat
  faces on the bed and a brim would reach the edge of the plate. Support is
  on, for the strip along each outer edge, which stands 3 mm off the bed so
  that it can land on the side's ledge, and under the right half's lap.
- **Faceplate** — stood on edge, **upside down**, and turned 45°. Lying flat
  it is 183 mm cornerwise and does not fit; on edge it is 165 mm and does.
  Upside down matters: the right way up, the flange that reaches back over
  the device is a 12 mm shelf hanging over nothing. Inverted, the flange lies
  on the bed and the part needs neither support nor brim.
- **Coupons** — standing as exported, like the side and leg they are cut
  from.

## Does it really fit the bed?

Fitting the bed is not the same as printing inside it: support and brim
reach past the part they belong to. `make plates` slices every plate with
Bambu Studio and reads the extents of what would actually be printed back out
of the G-code, ignoring the machine's own prime line.

| plate | X printed | Y printed | height | nearest bed edge |
|---|---|---|---|---|
| `side_l` | 9.4 – 172.5 | 6.1 – 174.0 | 44.4 | 6.0 mm |
| `side_r` | 6.0 – 173.9 | 7.5 – 170.6 | 44.4 | 6.0 mm |
| `leg_l` + `leg_r` | 42.0 – 138.0 | 38.7 – 141.3 | 44.4 | 38.7 mm |
| `tray_ucg_l` | 19.0 – 158.0 | 24.4 – 158.0 | 9.0 | 19.0 mm |
| `tray_ucg_r` | 19.0 – 161.0 | 24.4 – 160.6 | 9.0 | 19.0 mm |
| other tray halves | 19.0 – 161.0 | 21.9 – 158.1 | up to 19.6 | 19.0 mm |
| every faceplate | 7.7 – 172.3 | 7.7 – 172.3 | 44.4 | 7.7 mm |

Everything is inside 180 × 180 × 180. The sides are the tight ones.

## Fit adjustment

Printed fits depend on the printer. Every dimension is in
`common/src/params.py`; change it and rebuild with `make`.

| symptom | change |
|---|---|
| Side will not slide into its leg, or rattles in it | raise or lower `RUN_FIT` from 0.25 — try it on the two coupons in `common/stl/` first |
| Sides will not pass between the posts | lower `RAIL_T` from 3.2 |
| Rack screws will not line up | raise `SLOT_W` from 11.0 |
| Faceplate is tight between the sides | raise `PLATE_FIT` from 0.2 |
| Tray is tight between the rails | raise `TRAY_SIDE_FIT` from 0.2 |
| Tray halves will not close on each other | raise `LAP_FIT` from 0.3, `KEY_FIT` from 0.5 |
| Device is a tight push fit | raise `CLR_W` from 1.2 |
| Device rattles vertically | lower `CLR_H` from 0.8 |
| Catch is too stiff, or too weak | lengthen or shorten `CATCH_L` from 30 |
| Catch does not hold the frame | raise `CATCH_TOOTH` from 2.0 |
| Frame should draw out further before it stops | raise `CATCH_PULL` from 35; each millimetre leaves one less of tongue engaged |

## Slicing a 3MF from the command line

Two flags matter:

```sh
bambu-studio --arrange 0 --export-3mf out.3mf in.3mf   # keep the placement
bambu-studio --arrange 0 --slice 0 --outputdir out/ in.3mf
```

Without `--arrange 0` the CLI re-arranges everything on load whatever the
file says, which makes it look as though the plating had been ignored. It
also writes thumbnails and slice data back into the file it is given, so
slice a copy.

Three errors bite, none of which say what they mean:

- **"The 3mf file has invalid config, load geometry data only"** — the file
  is not a project. Bambu Studio keeps the meshes and throws the plates and
  the per-object settings away. It wants a complete
  `Metadata/project_settings.config`; `common/tools/a1mini_project.json` is
  one, and `common/tools/plate.py` embeds it.
- **"G-code conflicts detected after slicing"** — either a prime tower has
  landed on a part, or two parts' brims have run into each other. The project
  is cut to a single PETG slot with the tower off, and the plater keeps parts
  12 mm apart.
- **"Nothing to be sliced…"** or **"some objects are located over the
  boundary of the heated bed"** — the plate grid. Plates sit three to a row,
  216 mm apart each way; land outside that and parts are silently dropped or
  measured against the wrong origin. See `plate_origin()` in
  `common/tools/plate.py`.

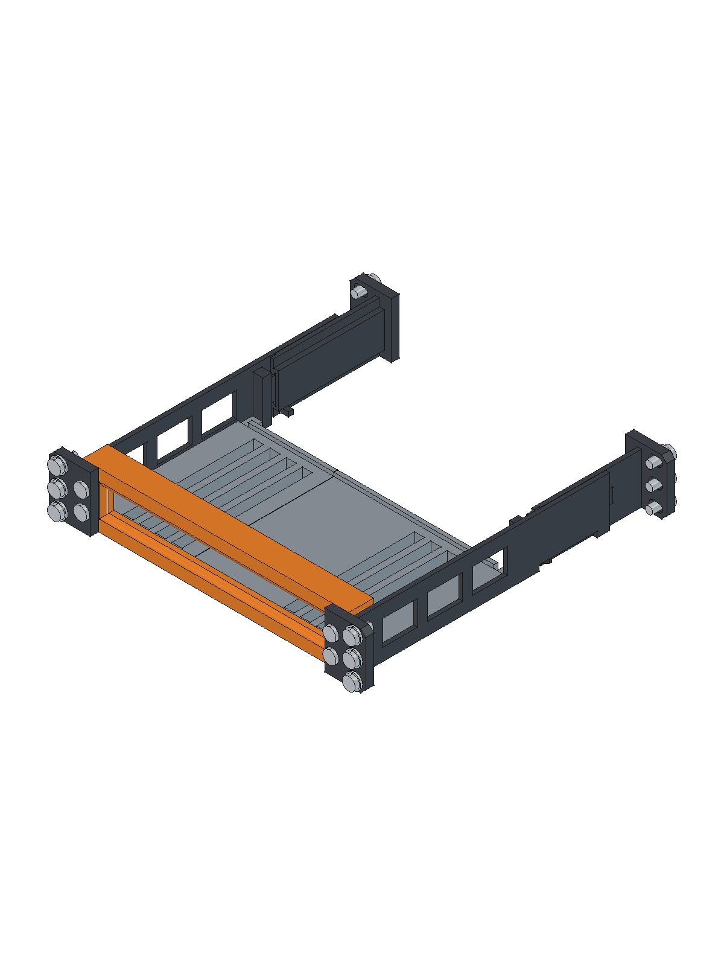
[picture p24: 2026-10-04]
nuc6i7kyk/images/makerworld-nuc-empty.png

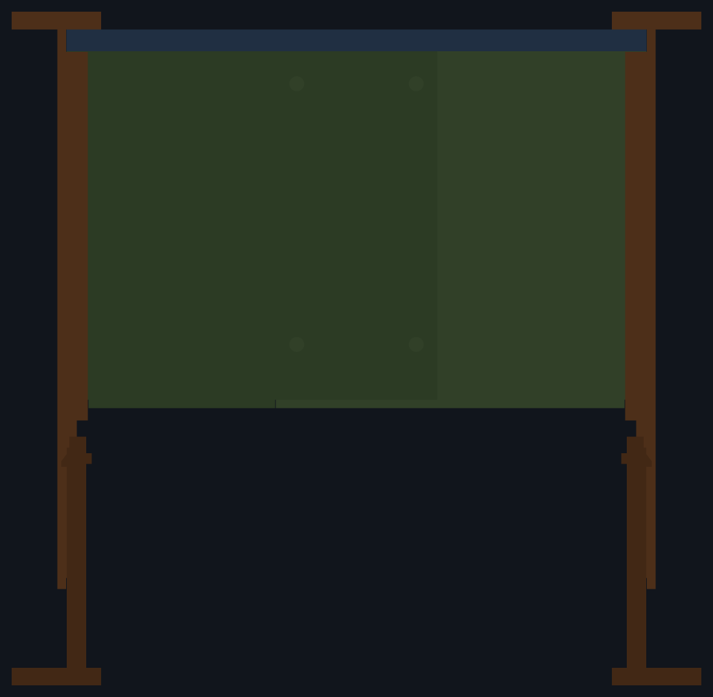
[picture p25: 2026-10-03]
ucg-fiber/images/assembly-ucg-top.png

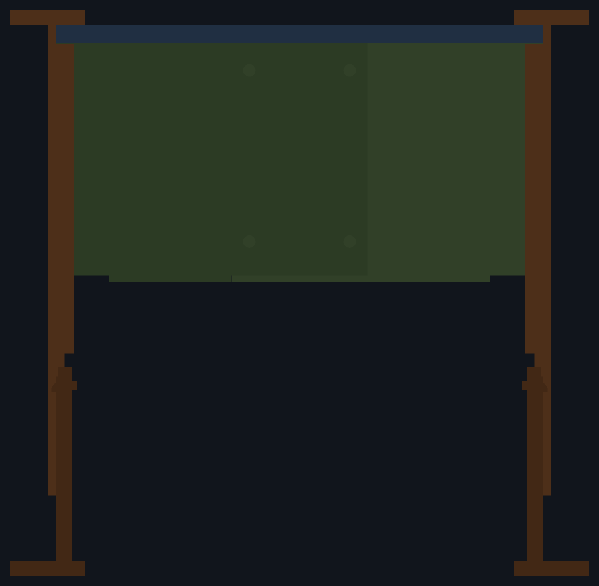
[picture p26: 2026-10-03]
tl-sg108e/images/assembly-sg108e-top.png

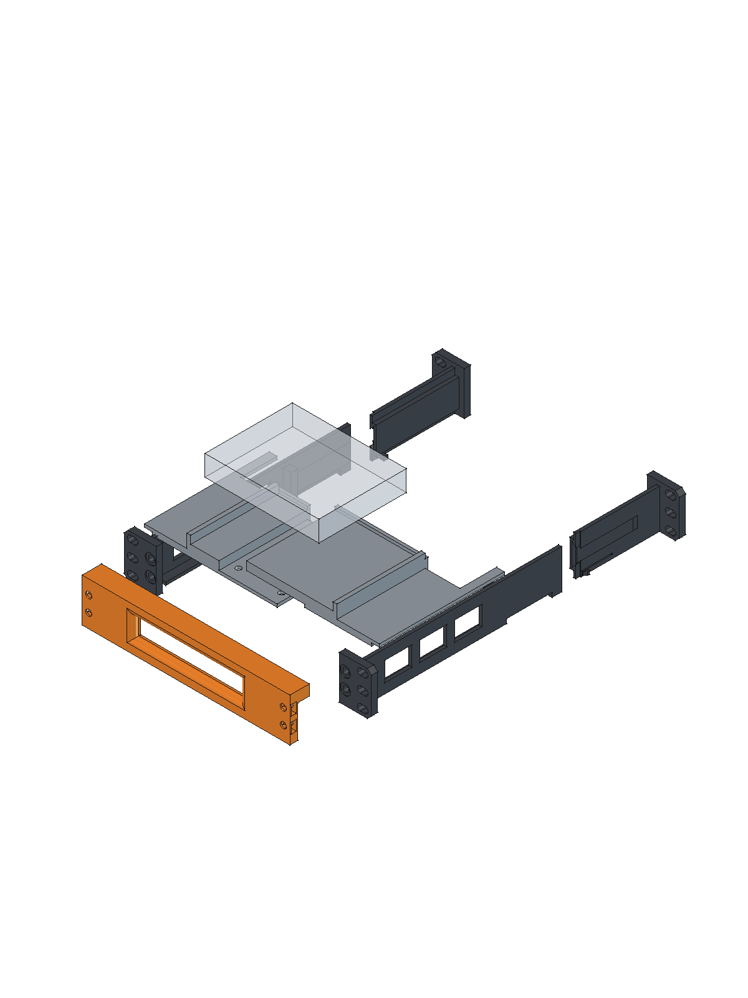
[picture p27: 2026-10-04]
usw-flex-mini/images/makerworld-usw-exploded.png

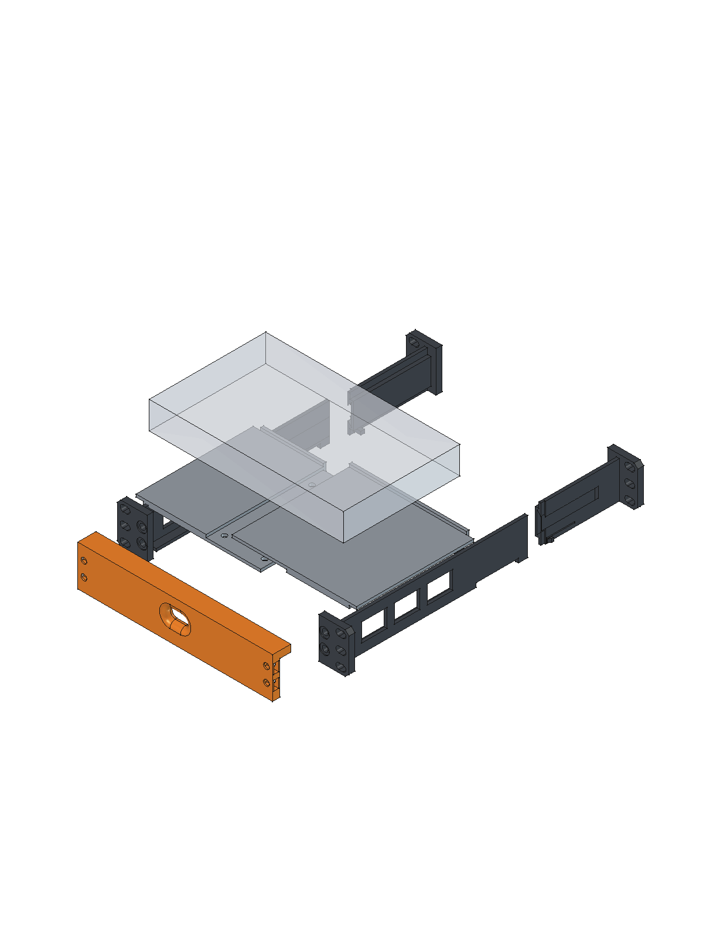
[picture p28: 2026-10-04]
ucg-fiber/images/makerworld-ucg-exploded.png

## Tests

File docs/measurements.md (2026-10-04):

# Where the numbers came from

The Lab Rax documentation quotes rounded figures ("222 mm between posts"), and
the rack is itself a 3D print, so the interface dimensions in
`common/src/params.py` — the ones tagged `[rack]` — were measured off the
published models instead. This records what was measured and how, so it can be
re-checked against a newer release of the rack.

## Reproducing it

The rack's files are not in this repository. Download the
[bolted 5U rack](https://makerworld.com/en/models/1464819-lab-rax-10-server-rack-bolted-version-5u)
from MakerWorld, then:

```sh
python3 common/tools/measure_rack.py <file.3mf | part.stl | object.model>
```

It needs Python 3 with NumPy. Holes are found by collecting triangles whose
normal is perpendicular to a candidate axis, grouping them by shared vertices,
and fitting a circle to each group. A group whose fit residual stays under
0.25 mm is a real hole rather than a rounded corner.

Three files were measured:

| file | what it is |
|---|---|
| the rack's A1 mini 3MF | the complete Lab Rax 5U rack, bolted version, plated for an A1 mini |
| its post joiner | the part that joins rack pieces too large for the bed |
| a Lab Rax 1U mount | a published mount for another device, as a second witness to the rack's interface |

The rack 3MF's `Metadata/model_settings.config` names each object. The posts
are `5U Vertical Post - A/B.stl`, the upper and lower halves of one post split
to fit a 180 mm bed. To measure one on its own, unpack the 3MF and point the
tool at its object file:

```sh
unzip -q rack.3mf -d rack/
python3 common/tools/measure_rack.py rack/3D/Objects/object_81.model
```

## Vertical hole spacing — EIA-310

The post carries seven holes over an 88.90 mm span, which is exactly 2U. Their
measured gaps:

```
15.902   15.902   12.646   15.902   15.902   12.646
```

against EIA-310's `15.875 / 15.875 / 12.700`. The 0.03 mm difference is the
mesh's circle discretisation, not the design. Within one 44.45 mm U that puts
holes at **6.35 / 22.225 / 38.1 mm** from the bottom of the U.

The 1U mount agrees: its three slots per side are centred 6.325 / 22.225 /
38.125 mm up from the bottom of its U.

## The posts hold the nuts

Each equipment hole is ⌀7.60 for the first 2 mm from the post's outer face and
⌀11.65 for the next 4 mm. That is not a counterbore for a screw head: slicing
the post across the wider zone gives boundary radii alternating 5.04 and 5.82
at 30° intervals, which is a **hexagon 10.09 mm across the flats and 11.65
across the corners** — an M6 nut pocket. The hole is blind at 6 mm.

So a rack screw goes in from **outside the rack** and threads into a nut the
post already holds. Equipment mounted in a Lab Rax needs clearance holes and
nothing else. The post joiner carries the same pocket.

## Width — 222.25 mm between the posts

The two columns of equipment holes are **236.525 mm** apart, and the posts
leave **222.25 mm** clear between them. The bracket's body is 220.4 mm wide,
0.925 mm clear of each post.

## Depth — 170.0 mm between the posts

Three separate frame members in the rack's 3MF are 170.0 mm long, and that is
the clear gap between the front posts and the rear ones.

Two things about depth are easy to get wrong:

- **The side panel is not the gap.** `Side Panel Half.stl` measures 175.9 mm
  front to back, but the panel is 3 mm thick and seats about 2.95 mm into a
  groove at each end: 170.0 + 2 × 2.95 is 175.9 exactly.
- **The post's depth is not settled by the mesh.** Its section is 30 × 35 mm
  and nothing in the print plate says which way it faces, so the distance
  over the outside of the posts is either **230** or **240 mm**.

The model takes the midpoint, 235 mm, as `RACK_D`. It has not been measured
on an assembled rack, and it does not need to be right: the joint between
each side and its rear leg slides, and covers 229 – 257 mm.

## Faceplate envelope — 254 × 44.45 mm

The 1U mount measures exactly 254.00 × 44.45 mm across its face. Its ears are
4.5 mm thick and its mounting holes are **slots, 11.4 × 7.4 mm**, centred
238.125 mm apart — 1.6 mm wider than the posts' 236.525, which the slots
absorb. That a working Lab Rax part slots its holes this generously is why
this bracket slots its own, 11.0 × 6.6 mm, and why 3.2 mm of material outboard
of the slot is acceptable (that mount leaves 2.24 mm).

## The devices

Case dimensions are the manufacturers' published figures:

| device | size (mm) | mass | source |
|---|---|---|---|
| UCG-Fiber | 212.8 × 127.6 × 30.0 | 734 g | Ubiquiti; mass with an SSD fitted |
| USW-Flex-2.5G-5 | 117.1 × 90.0 × 21.2 | 206 g | Ubiquiti |
| TL-SG108E | 158 × 101 × 25 | 250 g, estimated | TP-Link, who publish no weight |
| NUC6i7KYK | 211 × 116 × 28 | 700 g, estimated | Intel, who publish no weight |

The masses only feed the load checks, where the gateway's 734 g is the
heaviest case.

### The gateway's display

Measured on the device with callipers: the display is a **21.0 × 10.0 mm
stadium**, centred on the case's width. It is the only feature on the front
face — no reset button, and the power jack is at the back with the ports —
which is what lets the faceplate be solid apart from one window.

The window is 22.5 × 11.0 mm, larger all round, because the gateway can shift
0.6 mm either way between the rails and a window cut to the display's own
size could clip it.

Its height is given by a rule about the faceplate rather than by a
measurement of the case: **the window's top edge sits 7.0 mm below the
underside of the flange** that reaches back over the gateway. That puts the
window's centre 24.3 mm above the bottom of the U, or 18.3 mm above the
bottom of the case. `make verify` measures the 7.0 mm on the built solid.
If your unit's display sits elsewhere, change `top_gap` in
`ucg-fiber/device.py`.

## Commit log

2026-09-08 Add 1U UCG-Fiber bracket for the Lab Rax 10" rack
    A script-generated FreeCAD model: src/params.py holds every dimension and
    src/model.py builds the solids from it, so the geometry follows the numbers
    rather than a drawn sketch.
    The gateway is 212.8 mm wide and the rack posts are 222.25 mm apart, which
    leaves 4.7 mm a side and drives most of the design. 212.8 mm will not fit a
    180 mm bed in any orientation, so the bracket is modelled as one 254 mm solid
    and then divided into printable parts by intersecting it with region solids --
    the mating faces cannot drift apart when a dimension changes. Six prints, four
    of them distinct: a vented tray, a top bar, two ear brackets and two rear
    stops.
    Ra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
    [UCG_Fiber_LabRax.FCStd, UCG_Fiber_LabRax.step, ear_l.stl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]
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2026-09-08 Make the plated 3MF a reproducible build
    The zip stored the current time on every entry, so re-running the export
    showed up as a modified file even when the geometry had not changed. Entries
    now carry a fixed timestamp. FreeCAD's own outputs still embed a build time;
    noted in the README.
    [UCG_Fiber_LabRax-A1mini.3mf]
2026-09-08 Orient top_bar and the stops so nothing prints over air
    Slicing the plated 3MF turned up two more floating islands.
    top_bar was being printed the right way up, where its rear flange starts
    2.8 mm above the bed with nothing under it -- a 14 x 172 mm ledge over air.
    Inverted, the flat face that forms the top of the 1U lies on the bed and every
    feature builds upward.
    The stops had been rotated onto their backs to put the upright's load across
    the layers, but that left 16 mm of the upright unsupported. Left as modelled,
    the upright and the foot both start at the floor line and the whole part
    builds off the bed. It is tall for its footprint, so it wants a brim.
    Bambu Studio now slices both pla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
    [UCG_Fiber_LabRax-A1mini.3mf]
2026-09-08 Make the plated 3MF a real Bambu Studio project
    Bambu Studio was refusing the file with "The 3mf file has invalid config, load
    geometry data only", so it kept the meshes and threw away the plates, the
    placement and the per-object support flags -- everything the plating was for.
    A 3MF needs a complete Metadata/project_settings.config before Bambu Studio
    will treat it as a project rather than an import. tools/a1mini_project.json is
    one, taken from the stock Lab Rax rack project, and tools/plate.py now embeds
    it along with the BambuStudio namespace and version markers it looks for.
    This also corrects an earlier misreading. `bambu-studio --export-3mf`
    re-arranges on load unless `--arrange 0` i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
    [UCG_Fiber_LabRax-A1mini.3mf]
2026-09-08 Bolt the parts together with trapped hex nuts
    The ears had no way to be fastened to the tray or the top bar: the joints were
    M3 screws self-tapping into printed pilot holes, which is both weak and not
    how Lab Rax does it. Every joint is now a bolt through a clearance hole into a
    hex nut sitting in a pocket, modelled from the trap on
    Bolted+Version+Post+Joiner.stl -- a 6.40 mm clearance hole 2 mm deep, then a
    hexagon 11.65 mm across corners and 5 mm deep.
    A trapped M6 nut wants about 13 mm of material around it. The faceplate rails
    are 8.0 and 10.45 mm tall, so the faceplate joints are M3 -- four per side,
    two in each rail, with the nut fed in from whichever outside face of the 1U is
    nearer.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
    [UCG_Fiber_LabRax-A1mini.3mf, UCG_Fiber_LabRax.FCStd, UCG_Fiber_LabRax.step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]
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2026-09-09 Rebuild the bracket around all four rack posts
    Started again. The bracket now bolts to the front and the rear rails, so both
    ends carry ears, and it is no longer a cantilever hanging off the front.
    Every rack screw is an M6 driven from outside the rack inwards into the hex
    nut the post already holds -- measuring the post confirms it: from its outer
    face, a 7.60 clearance hole 2 mm deep, then a hexagon 10.09 across flats and
    5 mm deep. So the ears only need clearance slots, and the earlier reading of
    that pocket as a counterbore was wrong.
    Four parts. Each side is one piece: front ear, rail, rear ear, the shelf the
    device sits on, and the rear stop. The top bar comes in halves because a
    ful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
    [UCG_Fiber_LabRax-A1mini.3mf, UCG_Fiber_LabRax.FCStd, UCG_Fiber_LabRax.step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]
2026-09-09 Add the tray, and bring the docs over to the four-post design
    The device was standing on two 11 mm ledges with nothing between them. It now
    stands on a tray.
    At 214 mm the tray will not fit a 180 mm bed in any orientation, so it comes
    in halves that lap on the centreline, each lapping the other way onto its
    side's ledge. The side's ledge is an L in section: a full-height nib in front
    of the device, then the shelf itself, so the nib and the rear stop hold the
    tray fore and aft and it needs no fixing to the sides. The halves bolt to each
    other through tabs that reach forward and back out of the device's footprint,
    where there is room to work and to drop an M3 nut into a slot -- the tabs
    stand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
    [UCG_Fiber_LabRax-A1mini.3mf, UCG_Fiber_LabRax.FCStd, UCG_Fiber_LabRax.step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]
2026-09-09 Put M6 through the tray joint, and move it behind the device
    The tray tabs were sized for M3 and could not have taken the M6 they were
    meant to. An M6 nut needs 10.2 mm of slot across the flats and 15.5 mm of
    height once its corners and a wall are counted; the tabs offered 8.0 and 10.0.
    It failed in two directions at once.
    The room is not at the front. Between the rack face and the device's front
    there are 8 mm, and nothing that takes an M6 fits in 8 mm without standing in
    front of the device's face. Behind the device there are 38.9 mm, so both bolts
    move there: one tab per half, side by side, 30 mm deep and 16 mm tall, with
    two M6 running across the joint and their nuts dropped in from abo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
    [UCG_Fiber_LabRax-A1mini.3mf, UCG_Fiber_LabRax.FCStd, UCG_Fiber_LabRax.step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]
2026-09-09 Widen the tray lap, and stop pretending a bolt fits at its front
    There is no bolt at the front of the tray joint and there cannot be one. An M6
    nut needs 15.5 mm of height once its corners and a wall are counted; the tray
    is 6 mm thick, and anything standing above it there stands in front of the
    device's face -- over the display, or over whichever ports sit low and
    central. Depth was never the problem: there are 16 mm between the rack face
    and the device. Height is.
    So the joint carries the front instead of a fastener. The centre lap goes from
    30 mm to 60 mm, runs the full depth, and is closed by the device's own weight
    and clamped by the two M6 behind the device. A second peg joins the fir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
    [UCG_Fiber_LabRax-A1mini.3mf, UCG_Fiber_LabRax.FCStd, UCG_Fiber_LabRax.step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]
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2026-09-09 Lap the top bar's halves, and give the bar room to go in
    The two halves only touched. Each hung off the single M6 at its own end, which
    is a pivot: the bar could rotate about it, sag in the middle, and open the
    seam. Butted like that the joint carried nothing at all.
    They now lap across the centre 50 mm -- the left half is the front web there
    and the right half the flange behind it -- and two M3 pull them together. That
    makes one beam held at two points 206 mm apart, which cannot pivot. M3 rather
    than M6 because the bar is 7.65 mm tall between the device and the top of the
    U: an M6 nut is 11.55 across the corners and will not go in at any angle,
    where an M3 is 6.35 and drops into a slot ope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
    [UCG_Fiber_LabRax-A1mini.3mf, UCG_Fiber_LabRax.FCStd, UCG_Fiber_LabRax.step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]
2026-09-09 Check that the gateway cannot leave through the front
    Asked whether the geometry holds the device in at the front, the answer turned
    out to be yes, but nothing had tested it and the reason is not what it looks
    like from the outside. It is the top bar's end blocks: they are 20.75 mm tall,
    they sit in the 8 mm between the rack face and the device, and each covers the
    outer 10.4 mm of its face over Z 23.7 to 36. Sweeping the device forward, it
    moves its 1.4 mm of fore-and-aft clearance and then stops against them, with
    537 mm3 of engagement each end.
    Three checks now push the device 1.5, 5 and 20 mm forward and require the
    assembly to be in the way, and a fourth requires the end blocks to be s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
    [UCG_Fiber_LabRax.FCStd, UCG_Fiber_LabRax.step]
2026-09-09 Make the top bar one piece
    Two halves meant a joint in the middle of a beam, and every way of making that
    joint was a compromise. Butted, each half hung off the single M6 at its own
    end and pivoted on it. Lapped and bolted, it held -- but only with two M3, the
    last non-M6 fasteners in the design, and only because an M3 nut is 6.35 across
    the corners where the bar is 7.65 tall.
    One piece has neither problem. At 220.4 x 20 mm it does not fit a 180 mm bed
    square on, but turned 45 degrees its footprint is 167.7 mm, and printed upside
    down the face that was the top of the 1U lies flat on the bed -- full contact,
    no support, no brim, 6.4 mm to the nearest plate edge. Trimming the flange
    from 17 m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
    [UCG_Fiber_LabRax-A1mini.3mf, UCG_Fiber_LabRax.FCStd, UCG_Fiber_LabRax.step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]
2026-09-09 Bring the README up to date, and give the tray room to drop in
    The README still described six parts, a top bar in halves, and a five-body
    model. It also never got the table of what holds the gateway in each
    direction: that edit was written against text that had already changed, the
    replacement silently matched nothing, and the commit claimed it had landed.
    Every number in the file is now checked against src/params.py -- 31 of them,
    all agreeing.
    The assembly section is now a procedure rather than a paragraph: what hardware
    to have to hand, the two nuts that have to go in before anything is bolted
    together and which way they drop, the order the parts go in and why the
    gateway has to come bef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
    [UCG_Fiber_LabRax-A1mini.3mf, UCG_Fiber_LabRax.FCStd, UCG_Fiber_LabRax.step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]
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2026-09-10 Reach the rear posts: the rack is 245.9 mm deep, not 175.9
    The bracket stopped 27 mm short of the rear posts. 175.9 mm is the side
    panel, and a side panel fits BETWEEN the posts, so it is the rack's INNER
    depth. I read it as the outer one. Outer, front post face to rear post face,
    is 175.9 + 2 x 35 = 245.9.
    That will not print in one piece: a side would be 261.9 mm long and a 180 mm
    bed takes 225.6 even cornerwise. So each side is now two parts. The side
    carries everything that touches the device -- front ear, rail, the ledge the
    tray lands on, the rear stop -- and stops at 206 mm. A rear leg laps the inner
    face of its rail over 60 mm, bolts through two M6, and carries the rear ear.
    The sp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
    [UCG_Fiber_LabRax-A1mini.3mf, UCG_Fiber_LabRax.FCStd, UCG_Fiber_LabRax.step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]
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2026-09-10 Put the whole bracket on one screw: M6 x 12
    Five joints, five different screw lengths, one of them an M6x14 that is a
    nuisance to buy. They are all M6x12 now, and the design was changed to suit
    the screw rather than the other way round.
    The binding constraint is the rack post: its equipment hole is blind at 6 mm,
    2 mm of clearance and then a 4 mm nut pocket. Go in more than 6 mm past the
    ear and the screw hits the end of the hole and never clamps; less than about
    5 mm and it barely catches the nut. That fixes the ear at 6.5 mm, where a
    12 mm screw enters 5.5 mm with 3.5 mm of thread in the nut and half a
    millimetre to spare. The old 8 mm ear is what wanted the M6x14.
    The other joints were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
    [UCG_Fiber_LabRax-A1mini.3mf, UCG_Fiber_LabRax.FCStd, UCG_Fiber_LabRax.step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]
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2026-09-11 One faceplate instead of two bars, with a window for the display
    The bar above the gateway and the bar below it are now a single plate across
    the whole opening, with a stadium window for the display. It has no joint to
    open, it stops the gateway across its whole face instead of at four corner
    blocks, and it still stops the tray sliding forward. Seven printed parts
    instead of eight, six plates instead of seven.
    Measured on the device: the display is a 21.0 x 10.0 stadium, centred on the
    case's width, its centre 14.0 above the case's bottom -- and the case's bottom
    sits on the tray, so that height is fixed rather than floating. The window is
    22.5 x 11.0, larger all round, because the gateway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
    [UCG_Fiber_LabRax-A1mini.3mf, UCG_Fiber_LabRax.FCStd, UCG_Fiber_LabRax.step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]
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2026-09-12 Remove the tray centre bolts, key the halves with four pegs
    Both tray tabs snapped off the first time the centre bolts were tightened.
    The tab hung off a 10 x 3 mm neck with the bolt 6.5 mm above it and up to
    22 mm behind it, so nearly all the preload arrived as bending rather than
    as clamp. CalculiX put the yield load at 26 N (tray_l) and 33 N (tray_r)
    against roughly 1700 N from an M6 at 2 N.m -- 65x and 52x over -- with the
    peak stress at the Y=136.6 outer corner, which is exactly where they broke.
    The tab is deleted rather than enlarged. The two halves already lap over
    the middle 60 mm for the whole depth, the side rails hold them sideways,
    the faceplate and the rear stops hold them for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
    [UCG_Fiber_LabRax-A1mini.3mf, UCG_Fiber_LabRax.FCStd, UCG_Fiber_LabRax.step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]
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2026-09-12 The rack is 235 mm deep, not 245.9: shorten and slot the legs
    Bolted up on the real rack the bracket is too long -- the front ears sit on
    the front posts and the rear ears stand proud of the rear ones, with the
    splice wound fully in.
    The reading was wrong. 175.9 mm is the side panel, and the panel is not the
    gap between the posts: it is 3 mm thick and seats about 2.95 mm into a groove
    at each end. The gap it spans is 170.0, which is the length of three separate
    frame members in the rack's own 3MF (objects 11, 24 and 79), and 170.0 plus
    2 x 2.95 is 175.9 exactly. Taking 175.9 as the gap put the nominal 15.9 mm
    long, and the old +/-9.8 splice could not take that out.
    The post's cross-section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
    [UCG_Fiber_LabRax-A1mini.3mf, UCG_Fiber_LabRax.FCStd, UCG_Fiber_LabRax.step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]
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2026-09-13 Place the window by rule: oval top 5.0 mm below the top bar
    The previous move was built on a guess about why the window was low -- that
    the 14.0 mm reading had been taken to the oval's bottom edge rather than its
    centre. That was inference, not the requirement, and it landed 1.3 mm short.
    The requirement is a rule about the faceplate itself: the oval's top edge sits
    exactly 5.0 mm below the underside of the top bar, the flange that reaches
    back over the gateway at z = 36.8. So the window spans z 20.8 .. 31.8, centre
    26.3, and WIN_Z is derived from BAR_FLANGE_Z0 rather than from any reading
    taken off the case.
    That is the point of stating it this way: it is a property of the printed
    part, s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
    [UCG_Fiber_LabRax-A1mini.3mf, UCG_Fiber_LabRax.FCStd, UCG_Fiber_LabRax.step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]
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2026-09-13 Carry a second device: generalise the chassis, add the Flex Mini 2.5G
    The sides and the rear legs turn out not to depend on the gateway at all --
    only on the rack -- so a second device costs three prints rather than seven.
    What was device-derived and is not any more:
    BODY_HW was POCKET_HW + RAIL_T and POCKET_HW was (DEV_W + CLR_W)/2. The real
    constraint is the post: 222.25 between them, 0.925 of clearance a side, a
    3.2 rail inside that. Re-derived from the rack, BODY_HW is still 110.2000
    and POCKET_HW still 107.0000 -- a redefinition, not a change. The UCG-Fiber
    needing exactly 214.0 was a coincidence of a well-chosen device.
    The sides' ledge and rear stop read DEV_Y1 and DEV_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
    [UCG_Fiber_LabRax-A1mini.3mf, UCG_Fiber_LabRax.FCStd, UCG_Fiber_LabRax.step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]
2026-09-13 Rewrite the README around what the project now is
    It had grown by accretion over many changes and was describing an earlier
    bracket in places. Corrected while rewriting, all of it caught by checking the
    text against the model rather than by reading it:
    the rack's depth, still given as 245.9 outer from a 175.9 inner, when it is
    235.0 from a 170.0 clear gap -- the reading that made the bracket 16 mm too
    long was still being quoted as fact
    the splice adjusting +/-9.8, when both halves are slotted and it is +/-19.6
    "the seven bodies" and "all 22 fasteners", now ten and twenty
    the ears reaching to x = +/-98 and covering 8 mm of the gateway's ends, when
    they reach +/-94 and cover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
    [UCG_Fiber_LabRax.FCStd]
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2026-09-13 Fix the plate grid: three to a row, not two
    Opening either exported 3MF and slicing it failed on plate 3 -- "Nothing to
    be sliced, either the print is empty or no object is fully inside the print
    volume". Everything from the second row of the plate grid down was landing
    off the grid entirely.
    plate_origin put two plates to a row. Bambu Studio wants three. Found by
    generating candidates and handing each to the real slicer: two to a row fails
    at plate 3, three to a row with a 216 mm step in both axes slices all six.
    A 250 mm step -- the number the docstring claimed had been read out of Bambu
    Studio -- fails at plate 2, so that comment was wrong as well as the code.
    Nothing caught it because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
    [UCG_Fiber_LabRax-A1mini.3mf, USW_Flex_LabRax-A1mini.3mf]
2026-09-13 Keep slashes out of plate names
    Bambu Studio refuses a name containing <>:/\|?*" -- it turns a plate's name
    into a filename -- and says so with a dialog that lists the characters but
    not which name, which plate or which file it found them in. The plate labels
    added with the split read "Chassis 1/3 - left side", and the "1/3" was enough
    to trigger it on open.
    They are "1 of 3" now. Every name in both files was then checked against that
    rule -- file name, title, six plate names, eleven object names each -- and
    all are clean.
    plate.py refuses to write a file with such a name at all now, naming the
    offending string and the character, so the next one fails at the build rather
    than in a dialog t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
    [UCG_Fiber_LabRax-A1mini.3mf, USW_Flex_LabRax-A1mini.3mf]
2026-09-13 Carry a TP-Link TL-SG108E as well
    158 x 101 x 25, eight gigabit ports on the front, 5 V brick on the back, from
    tp-link.com. It sits inside the envelope the chassis offers with room to
    spare, so it cost a profile in devices.py and three prints: nothing in the
    sides, the legs, or either other device's parts moved a micron.
    Its tray lifts it 3.725 mm, which puts the case centred on 22.225 -- the U's
    centre exactly -- and walls 4 mm thick at x +/-79.60 hold it across the
    55 mm of slack it leaves in the bay. The rear lip goes at y 110.
    Its faceplate is a Frame like the Flex Mini's, but 25 mm of case height buys
    a proper border where 21.2 did not: 4 mm all round still leaves a 150 x 17
    opening,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
    [TL_SG108E_LabRax-A1mini.3mf, UCG_Fiber_LabRax.FCStd, UCG_Fiber_LabRax.step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]
2026-09-13 Carry an Intel NUC6i7KYK, and slot its tray
    211 x 116 x 28, 45 W, from intel.com. It fits the envelope, so the chassis
    does not change: all thirteen existing parts are byte-identical.
    Three things about it are unlike anything carried so far.
    It fills the bay. At 211 mm the sides' own rails hold it, as they do the
    gateway, so its tray needs no walls -- but the 3 mm it leaves across the
    214 mm bay is its clearance, not the 1.2 the others use, so the profile says
    so rather than leaving the check hunting for a number that is not there.
    It is not passive. A 45 W part with a blower takes its air in underneath, and
    a solid tray sits flat against that intake. Its tray is slotted: fore-and-aft
    slo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
    [NUC6i7KYK_LabRax-A1mini.3mf, UCG_Fiber_LabRax.FCStd, UCG_Fiber_LabRax.step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]
2026-09-14 Cut the flange back so the upper nuts can be fitted
    On the Flex Mini's faceplate the two upper nuts could not be got into their
    pockets. A nut is fed in from the rear, so it has to travel under the flange
    to reach its pocket -- and the flange sits on top of the device while the nut
    positions are fixed by the sides, which are shared. A short device pulls the
    flange down into that path. It sat 1.58 mm into it.
    The TL-SG108E was 0.32 mm clear, which is not clearance at all on a printed
    part. The gateway has 1.59 mm and the NUC 1.82, which is why neither showed
    it.
    Where the gap is under NUT_FEED_CLEAR the flange is now cut back at the two
    upper screws. It costs nothing: at x = +/-100 the flan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
    [TL_SG108E_LabRax-A1mini.3mf, UCG_Fiber_LabRax.FCStd, UCG_Fiber_LabRax.step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]
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2026-09-14 Stop the trays walking, and raise the Flex Mini's opening 1 mm
    Two faults reported from the printed parts.
    The tray slid inside the bracket. What locates a tray fore and aft is the
    strip riding the ledge -- the faceplate in front of it, the sides' rear stops
    behind -- and only a tray as deep as the bay reaches them. The gateway's does,
    so nothing showed it. The others did not: 38 mm of slack on the Flex Mini,
    27 on the TL-SG108E, 12 on the NUC. Every tray now carries that strip back to
    y 136.6 whatever its device's depth. The gateway's grows nothing and is
    byte-identical.
    The check that should have caught it compared the tray with the depth of the
    device it was drawn around -- which a tray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
    [NUC6i7KYK_LabRax-A1mini.3mf, TL_SG108E_LabRax-A1mini.3mf, UCG_Fiber_LabRax.FCStd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]
2026-09-14 Take the Flex Mini window's fillet back into the script
    A 6 mm round-over on the four front edges of the opening, matching the one
    the gateway's window has. It is in devices.py now, so a rebuild keeps it.
    The version in the FreeCAD file could not have been printed. A PartDesign
    dressup replaces the chain from its base onwards, and that fillet was based
    on the window pocket -- the second feature of seven -- so everything after it
    was dropped. The body came out 214 x 8.0 x 44.5 instead of 214 x 20 x 44.5:
    no flange, no screw holes, no nut pockets, nothing to bolt it on by. The
    script applies the round to the last feature instead, and says why.
    The fillet code also only understood a Window, w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
    [UCG_Fiber_LabRax.FCStd, UCG_Fiber_LabRax.step, USW_Flex_LabRax-A1mini.3mf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]
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2026-09-29 Give the chassis a common/ folder and each device a folder of its own
    The shared chassis and all the code move into common/: src/, tools/, the
    side and leg STLs, the FreeCAD document and the STEP. Each device gets a
    folder -- ucg-fiber/, usw-flex-mini/, tl-sg108e/, nuc6i7kyk/ -- holding its
    profile (device.py, cut out of devices.py unchanged), its tray and faceplate
    STLs, its 3MF and its renders.
    devices.py keeps the classes, loads each folder's device.py, and says where
    a part's files go, so build, plate and preview ask it rather than joining
    paths themselves. Adding a device is a folder and one name in DIRS.
    Rebuilt from the new layout: every STL, 3MF and render comes out
    byte-identical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
    [NUC6i7KYK_LabRax-A1mini.3mf, TL_SG108E_LabRax-A1mini.3mf, UCG_Fiber_LabRax-A1mini.3mf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]
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2026-10-04 Round over the front edge of the NUC's opening
    The gateway's window and the Flex Mini's frame have a 6 mm round-over; the NUC's opening was a hole punched in a plate. It gets 4 mm rather than 6: the opening ends at x = +/-89.5 and the faceplate's nut slots start at +/-93.87, so a 6 mm round would run its rim into them. 4 mm stops at 93.5 and leaves half the plate behind it.
    [NUC6i7KYK_LabRax-A1mini.3mf, NUC6i7KYK_LabRax.FCStd, NUC6i7KYK_LabRax.step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]
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
